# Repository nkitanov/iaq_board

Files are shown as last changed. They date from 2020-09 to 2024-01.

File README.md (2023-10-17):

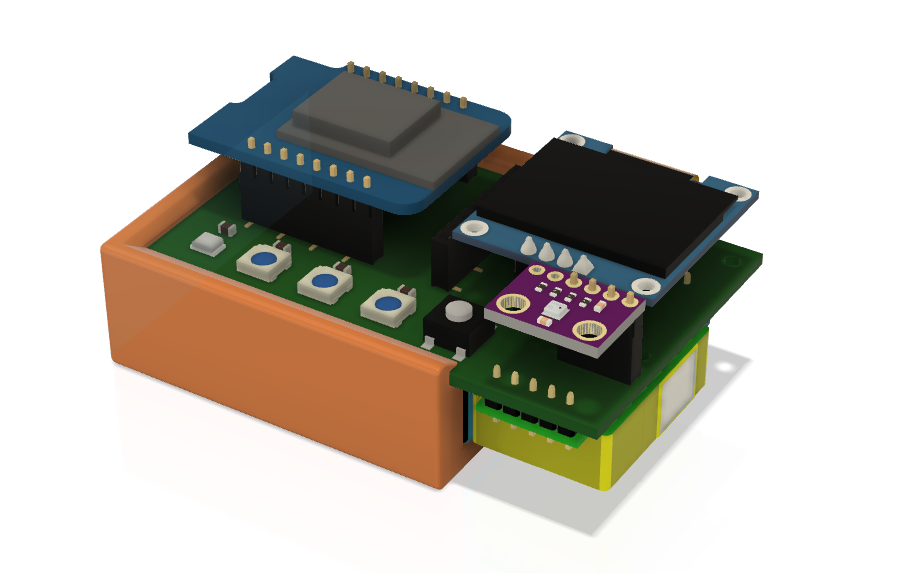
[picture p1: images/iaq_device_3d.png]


# IAQ (Indoor Air Quality) Board 
IAQ Board is a DIY (Do-It-Yourself) device for measuring internal air quality. I needed a device for measuring some air quality parameters which is **compact, cheap, simple and capable**. After I prototyped it, decided instead of mounting into some odd box with cables hanging inside between the sensors, why not just solder everything on a printed circuit board. I had some experience with this from the time when I was a student years ago and luckily now it's much easier to crate PCB and very cheap to get it printed. 

**And here is my device. I am publishing all the details and documentation under '[open source hardware](https://en.wikipedia.org/wiki/Open-source_hardware)' CC-BY-CA license, so everyone can build, adapt and sell it, as long as share under the same license**

**Table of Contents**
   * [IAQ (Indoor Air Quality) Board](#iaq-indoor-air-quality-board)
      * [What exactly is this thing?](#what-exactly-is-this-thing)
      * [Who can build it?](#who-can-build-it)
      * [What about ordering a device?](#what-about-ordering-a-device)
   * [Components Details](#components-details)
      * [1. PCB](#1-pcb)
      * [2. Holder case](#2-holder-case)
      * [3. Microcontroller Board](#3-microcontroller-board)
      * [4. Dust Sensor](#4-dust-sensor)
      * [5. CO2 sensor](#5-co2-sensor)
      * [6. Temperature/Humidity/Pressure sensor](#6-temperaturehumiditypressure-sensor)
      * [7. Ambient Light Sensor](#7-ambient-light-sensor)
      * [8. LEDs](#8-leds)
      * [9. Displays](#9-displays)
      * [10. Volatile Organic Compound sensor](#10-volatile-organic-compound-sensor)
      * [11. Other electrical components](#11-other-electrical-components)
      * [Can you skip components?](#can-you-skip-components)
   * [Bill of Materials (BOM)](#bill-of-materials-bom)
   * [Firmware](#firmware)
   * [Schematic](#schematic)
   * [Soldering tips](#soldering-tips)
   * [User manual](#user-manual)
         * [Multi function button](#multi-function-button)
         * [LED Brightness control and correction](#led-brightness-control-and-correction)
   * [FAQ](#faq)
            * [<em>Can I power it from a battery?</em>](#can-i-power-it-from-a-battery)
            * [<em>Can it be installed outdoors?</em>](#can-it-be-installed-outdoors)
            * [<em>How to calibrate MH-Z19B CO2 sensor?</em>](#how-to-calibrate-mh-z19b-co2-sensor)
            * [<em>How to calibrate SGP30 VOC sensor?</em>](#how-to-calibrate-sgp30-voc-sensor)
            * [<em>How to connect to WiFi?</em>](#how-to-connect-to-wifi)
            * [<em>How to add it in Home Assistant?</em>](#how-to-add-it-in-home-assistant)
            * [<em>What if some of the sensors/displays is disconnected while the device works?</em>](#what-if-some-of-the-sensorsdisplays-is-disconnected-while-the-device-works)
         * [<em>What about short circuits of the exposed electronics?</em>](#what-about-short-circuits-of-the-exposed-electronics)
   * [More Tech Details](#more-tech-details)
   * [Known issues](#known-issues)
   * [License](#license)

## What exactly is this thing?
The device is based on widely available and cheap essential components ([MCU](https://en.wikipedia.org/wiki/Microcontroller) and sensors). The core component is a simple [PCB](https://en.wikipedia.org/wiki/Printed_circuit_board) (printed circuit board) that's why I called it **IAQ Board**. The board integrates all the components in a very small footprint (size of a cigarette box). All parts are soldered on it and everyone can assemble it with basic soldering skills. The total price if you build it yourself is about 50-60 EUR. I also made simplistic holder for 3D print (6-7 EUR is you don't have a 3D printer). For these amount of money you get the following air parameters measured adequately (you might not install all sensors if you want to save money): 
- [X] ***Temperature / Humidity / Pressure***
- [X] [***Air particles PM1, PM2.5, PM10***](https://en.wikipedia.org/wiki/Particulates)
- [X] [***Carbon Dioxide with NDIR sensor***](https://en.wikipedia.org/wiki/Indoor_air_quality#Carbon_dioxide)
- [X] [***Air Quality Index by EPA, based on 24h average PM2.5 particles***](https://airindex.eea.europa.eu/Map/AQI/Viewer/)
- [X] [***Ambient light***](https://en.wikipedia.org/wiki/Illuminance)
- [X] [***Total VOC (volatile organic compound)***](https://en.wikipedia.org/wiki/Volatile_organic_compound)
- [X] ***equivalent CO2 (not very correct compared with the NDIR sensor, but it's provided by the VOC sensor)***

**On top of that:**
- [X] ***At least one OLED display to show the data (can have one more on the top of the MCU board)***
- [X] ***three RGB wide angle LEDs with auto brightness. LED1 indicates PM2.5, LED2 - Air quality index, LED3 - CO2.*** 
- [X] ***auto night dimming of the displays and LEDs (can be disabled)***
- [X] ***MIN/MAX values of Temperature, PM2.5 and CO2, and 24h average PM2.5 value.***
- [X] ***multi function button for selection of the data to show on the display***
- [X] ***[firmware](https://en.wikipedia.org/wiki/Firmware) based on [ESPhome](https://esphome.io/), the device can be [directly added](https://esphome.io/components/api.html) in [Home Assistant](https://www.home-assistant.io/)***
- [X] ***WiFi access to the device with http server and [REST API](https://esphome.io/web-api/index.html) and [esphome native API](https://esphome.io/components/api.html)  to read the sensor data***

Here is a video with all you need to know:

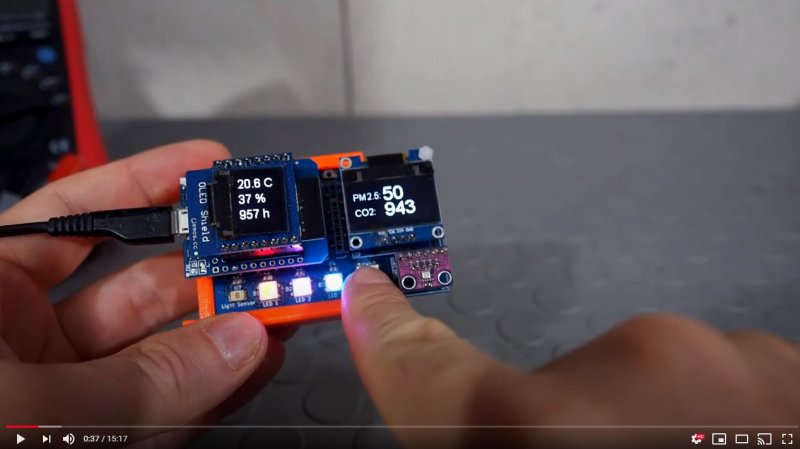
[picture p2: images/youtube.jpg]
Click to see the video (https://www.youtube.com/watch?v=X75OGs2TTT8)


## Who can build it?
The device is just a simple PCB board and almost everyone with some soldering skills can assemble it in a few steps:
1. [Download the PCB files](kicad/) and print the PCB somewhere like https://jlcpcb.com/
2. Buy some components (listed in the bill of materials section) from Aliexpress or any other source.
3. Solder everything on the board. With the exception of the ambient light sensor, all the rest is pretty easy with general soldering skills. Soldering light sensor can be done with regular soldering iron, but because of the small size of the IC, it's easier if you have heat gun or SMD reflow oven/plate. [Here is video how to complete device from assembled PCB.](https://www.youtube.com/watch?v=b2oDBgN3h1w)
4. Flash the microcontroller with the esphome firmware [following the manual](firmware/). You can write your own firmware if you have the skills. :smile: 
5. Print the holder case on 3D printer if you wish. I have some sensors without it and they are perfectly fine, so it's up to you.

If you have experience with electronics and microcontrollers just check the [schematics](kicad/) and make whatever you wish - build your own firmware, do another PCB, connect external sensors, don't use it at all because you can make it better :smile:. The device is quite simple for embedded electronics enthusiasts anyway...

## What about ordering a device?
I made this device for me and then decided to share it. I think a lot of people might be interested to have such air quality sensor. I did not have intension to make money from it, that's why it's "open hardware" and I publish all of the information, so everyone can build it. 

However I know that someone might be interested in the device, but lack the skills to build it. [Please follow this link for more details.](ordering.md)

# Components Details
The device with AAA battery size comparison:

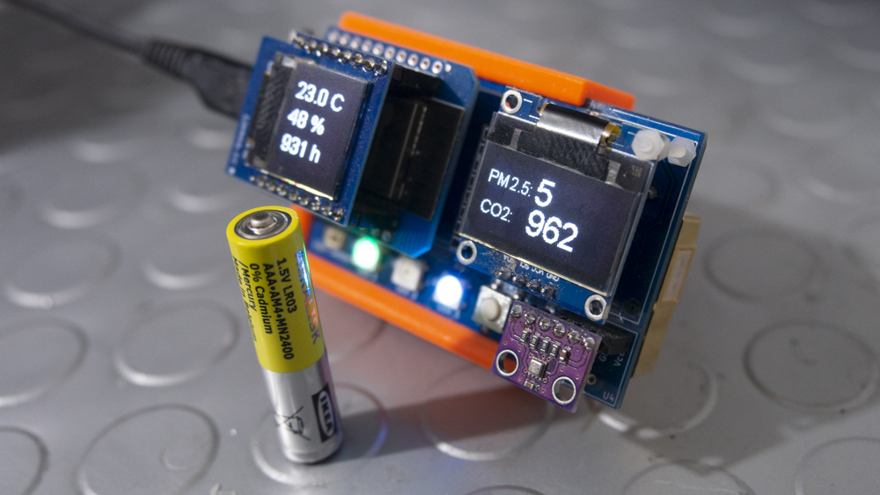
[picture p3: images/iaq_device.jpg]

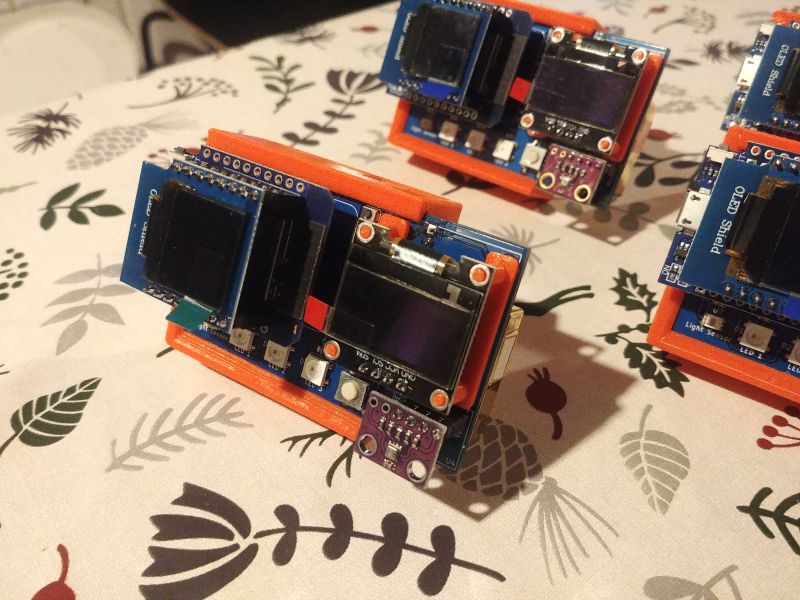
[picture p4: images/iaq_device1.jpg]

## 1. PCB
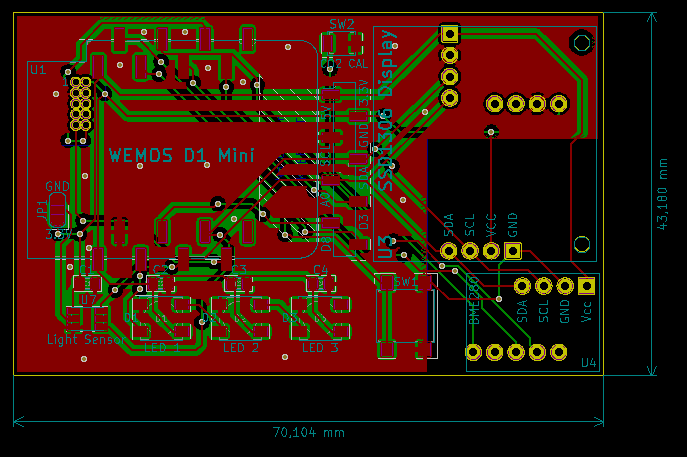
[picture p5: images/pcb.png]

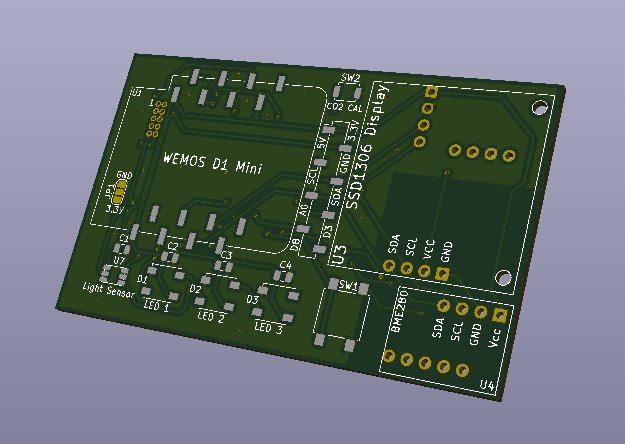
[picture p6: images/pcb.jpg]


The PCB (printed circuit board) is very simple and compact. It's 70x43mm (photos above are showing it larger than the actual size). It just connects a few sensors, microcontroller and displays. I wanted to integrate it in as much smaller footprint as possible, so the whole device is like a cigarette box. Most of the parts are surface mounted which makes the soldering just a bit more complicated, but still not a big deal. And of course it could be integrated even more by soldering all individual components on the PCB but then it's not really a hobby project anymore and much more difficult to build it.
It's designed on [KiCad](https://kicad.org/) and in the [kicad folder](kicad/) you can find full KiCad project, PCB gerber files, etc.
## 2. Holder case
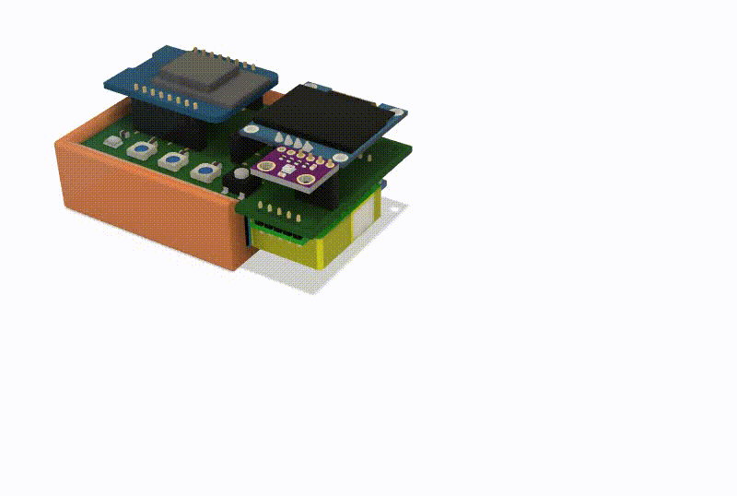
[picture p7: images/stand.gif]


For any device the box is important. However my idea was to expose the PCB and electronics as much as possible in order to simplify it. I like the "raw" view of electronics and in this form I find it beautiful. 

Taking into account this, I designed a simple holder case for "sliding" the PCB in it and holding the particle sensor. The case can stay at about 45 degrees angle. It is designed on Fusion 360 and the [details are here](case_model). The holder case is not perfect, I was thinking to redesign it but no time for this. I am sure someone can do it better. :smile: Or design a complete box to cover the electronics fully, for me it is better in this minimalistic style. 
## 3. Microcontroller Board
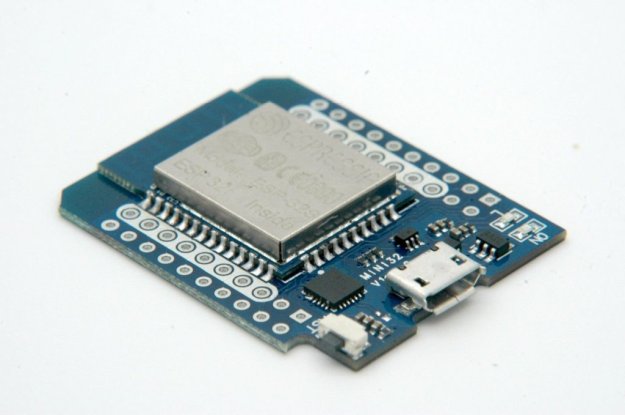
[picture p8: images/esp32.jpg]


Initially I developed the board with using the most popular WiFi enabled MCU [ESP8266](https://en.wikipedia.org/wiki/ESP8266) mounted on the cheap and small [Wemos D1 Mini board](https://docs.wemos.cc/en/latest/d1/d1_mini.html). However this MCU have some limitations described in the [tech details](#more-tech-details), so I changed it with the same size board compatible with Wemos D1 Mini, but running the newer much more powerful MCU of the same company - [ESP32](https://en.wikipedia.org/wiki/ESP32). In that way the device is quite stable, can run web server and since the board is having the same layout, on top of the D1 Mini ESP32 board you can connect extra display designed for d1 mini very easy. PCB is compatible with both D1 Mini ESP8266 or ESP32, even the labels are the same like on the older D1 board. However **I do not recommend to use D1 mini with ESP8266!** Also if I have to build next version of the PCB (I still have some 25 pcs), I will change the pins of one of the dust sensors.

These small size MCU board are pretty nice, they are tiny, have USB connector, onboard power supply and USB converter for programming or serial output. And you are powering the whole device just with a mini USB cable.
## 4. Dust Sensor
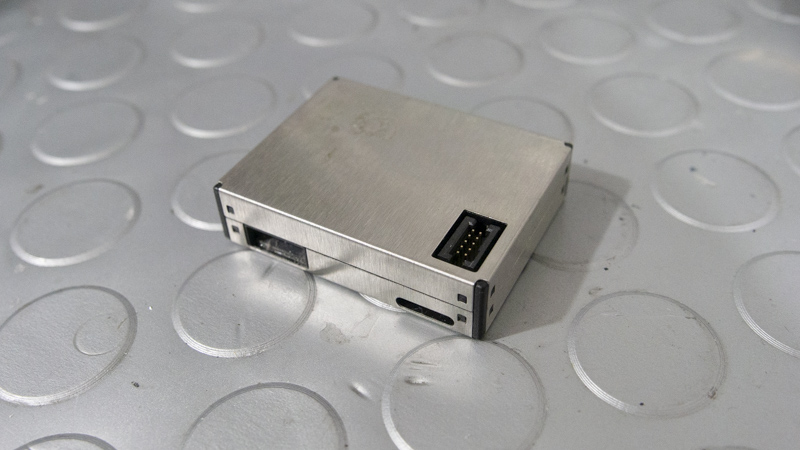
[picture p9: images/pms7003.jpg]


Dust sensor is the Chinese [Plantower PMS7003]([http://www.plantower.com/en/content/?110.html](https://www.plantower.com/en/products_33/76.html)) - 1, 2.5 and 10 micron particle laser sensor. It's very small and is perfect for indoor environment. 
## 5. CO2 sensor
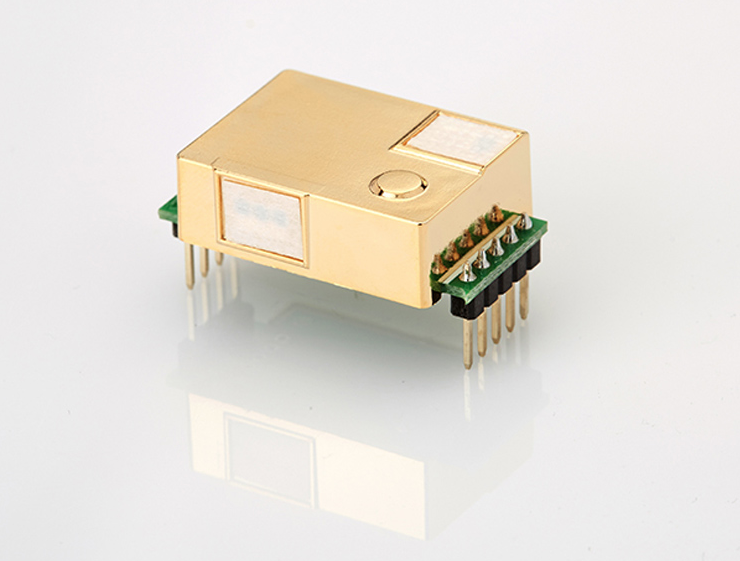
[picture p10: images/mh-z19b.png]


Carbon dioxide sensor is the Chinese [Winsen MH-Z19B](https://www.winsen-sensor.com/sensors/co2-sensor/mh-z19b.html) - the most expensive part of the device. It's quite popular for hobby air quality meters and can [adequatly measure](https://www.circuits.dk/testing-mh-z19-ndir-co2-sensor-module/) up to 5000 ppm CO2 concentration.

**Keep in mind that there are some fake MH-Z19B sensors, [explained here](https://revspace.nl/MH-Z19B#Fake_MH-Z19B_.28black_PCB.29).**
## 6. Temperature/Humidity/Pressure sensor
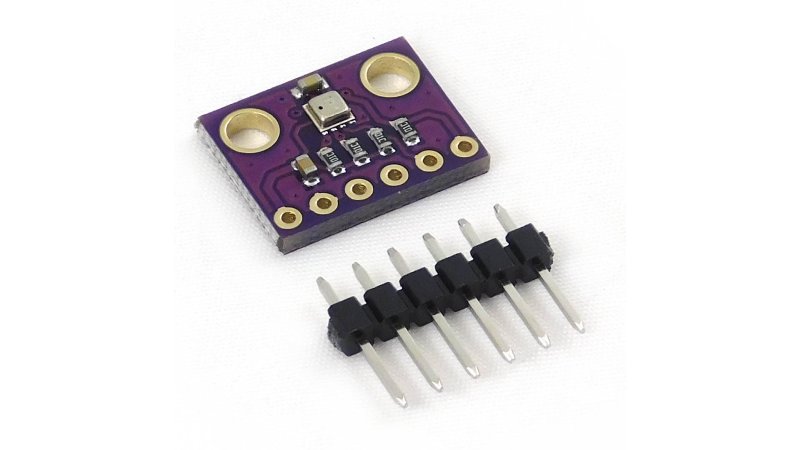
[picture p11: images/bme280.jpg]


This sensor is the popular [Bosch BME280](https://www.bosch-sensortec.com/products/environmental-sensors/humidity-sensors-bme280/), mounted on 3.3V only breakout board from China. There are also smaller [breakout boards](http://www.cncroutersource.com/breakout-boards.html) from China working both on 5V and 3.3V, but these have voltage regulator which can theoretically warm the board and change the temperature reading. That's why I use the boards with 3.3V only.

**Please note that due to semiconductor shortage these are difficult to find now (June 2021). I am currently using my own breakout where I solder the BME directly. BME280 as IC can be found occasionally in stock from DigiKey**
## 7. Ambient Light Sensor
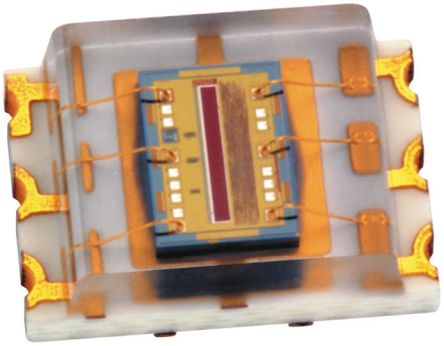
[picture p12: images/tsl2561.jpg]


The light sensor is [TSL 2561](https://ams.com/tsl2561) and it's the only sensor you need to solder directly on the board without a breakout board. I added this sensor not because I need to measure the ambient light but because I am a brightness freak, and I need the LEDs brightness to depend on the ambient light. Also wanted during the night when the lights are off the device to turn off the LEDs and displays automatically. You can also change the behavior of this brightness control and I spend some extra time developing the config only for the brightness features. :smile:
## 8. LEDs

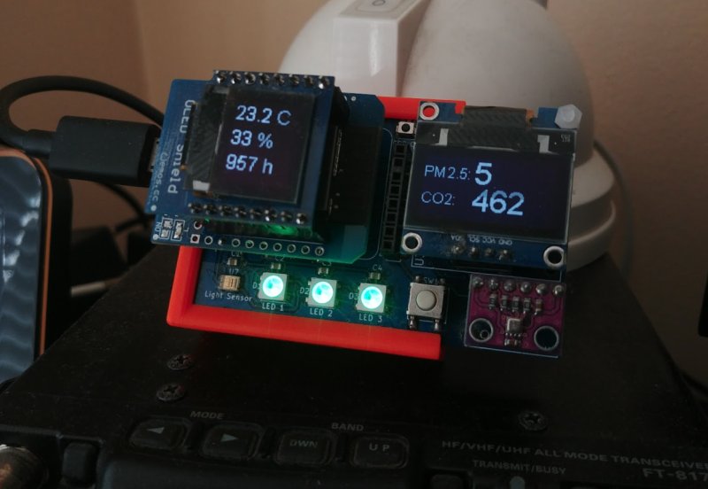
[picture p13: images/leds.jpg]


The device have three [Neopixel 5050](https://www.digikey.com/catalog/en/partgroup/neopixel-rgb-5050-led-with-integrated-driver-chip-100-pack/70939) RGB multicolor LEDs. These LEDs are mostly found in the colorful LED strips and are controlled over a single wire. In my esphome based firmware left LED color is indicating the level of PM2.5 and change the colors depending on the value. Middle (LED2) indicates Air Quality Index based on PM2.5 only and the right one (LED3) indicates CO2 value. Keep in mind PM2.5 values are close to [EEA](https://www.eea.europa.eu/) levels (especially AQI). Some other devices like Xiaomi Air Purifiers have some very high levels on their displays and logic - it's green up to 70 microns which is already considered unhealthy both by EEA and EPA. In China "healthy" is considered bellow 50 microns. That's why AUTO mode of these Chinese devices [works so bad](https://smartairfilters.com/en/blog/xiaomi-auto-mode-leaves-air-unsafe-86-hours/). I try to keep indoor PM2.5 around 5-10 microns. I normally control my purifiers by Home Assistant and do not rely on their auto logic. If you have Xiaomi Purifier it can still show green, and the iaq device shows stable red, but it is correct according to the EU regulations.

**Colors of the LEDs depends on this table:**
PM2.5 value (um/m3)<br>LED 1 | [AQI by EEA (Air Quality Index for PM2.5 24h average)](https://airindex.eea.europa.eu/Map/AQI/Viewer/)<br>LED 2 | CO2 value (ppm)<br>LED 3 | Color |  R  |  G  |  B
:-----------------: | :-------------: | :-------------: | :---: | :-: | :-: | :-: 
< 10 | < 10 (Good) | < 700 |  | off | on | off 
11 - 20 | 10 - 20 (Fair) | 700 - 1000 |  | off | on | on 
20 - 30 | 20 - 25 (Moderate) | 1000 - 1500 |  | on | on | off 
30 - 40 | 25 - 50 (Poor) | 1500 - 2100 |  | on | off | on 
\> 50 | > 50 (Very Poor) | > 2100 |  | on | off | off 

## 9. Displays
The main display is the popular SSD1306 128x64 OLED display. On the top of the MCU board you can install extra [OLED 63x48](https://docs.wemos.cc/en/latest/d1_mini_shiled/oled_0_66.html) shield from Lolin which shows temperature, humidity and air pressure only.
## 10. Volatile Organic Compound sensor
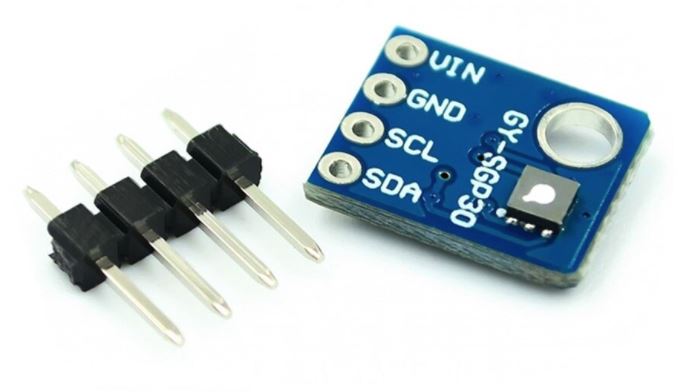
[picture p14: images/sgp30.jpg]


This is the [Sensirion SGP30](https://www.sensirion.com/en/environmental-sensors/gas-sensors/sgp30/) senor mounted on a breakout board from China. I do not use it on all my devices, but I added it because I can. :smile: Also with it the device measures almost completely the internal air quality. SGP30 is also showing equivalent CO2 based on VOC but it's not precise compared with MH-Z19B NDIR sensor. Also it needs periodic calibration hardcoded in the firmware which makes it more tricky to use.

Please [check here](https://github.com/nkitanov/iaq_board/issues/10#issuecomment-798994427) for the known issues with these boards.
## 11. Other electrical components
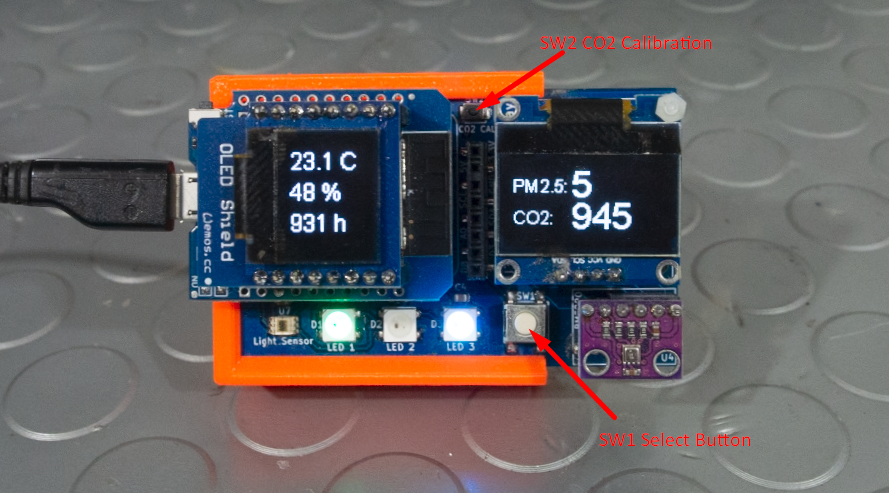
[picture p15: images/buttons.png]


The device have 2 buttons - one for selection screens and settings, and another micro button for calibration of the CO2 sensor to 400ppm if you keep it pressed for more than 7 sec. 

There are also four [surface mounted](https://en.wikipedia.org/wiki/Surface-mount_technology) [bypass capacitors](https://en.wikipedia.org/wiki/Decoupling_capacitor) for the ambient light sensor and the LEDs.

## Can you skip components?
Yes. The minimum you need is the [microcontroller board](#3.-microcontroller-board). However since you don't have any sensors, you won't get any data. :smile: You can add only the sensors needed. Also if you skip ambient light sensor there will be no auto brightness control and the LEDs will operate always at 25% intensity. Installing only the ambient light sensor without any of the displays or any of the other [I2C](https://en.wikipedia.org/wiki/I%C2%B2C) sensors (BME280, SGP30) will not work as there are no [pullup resistors](https://en.wikipedia.org/wiki/Pull-up_resistor) on the PCB for the I2C bus since it uses the resistors of the external breakout boards.

# Bill of Materials (BOM)
Bellow is the list of all parts needed to assemble the device with links to sources where you can get them. Of course other sources can be used, just pay attention that the items are identical with the listed bellow. For example the SSD1306 display can be found with similar physical look and dimensions, but pins are not the same.

Schematic Ref | ITEM | pcs | Comment
--------------| ---- | :-: | -------
| | PCB Board | 1 | in [kicad folder](kicad) you can find all the data and GERBER PCB design files
U1 | [WeMos_D1_mini_ESP32](https://www.aliexpress.com/item/4000880936043.html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,searchweb201602_,searchweb201603_) | 1 | [ESP8266 version](https://www.wemos.cc/en/latest/d1/d1_mini.html) also can work but not recommended 
U2 | [PMS7003 Sensor](https://www.aliexpress.com/item/32832444694.html?spm=a2g0s.9042311.0.0.27424c4dKxsO6Z) | 1 | don't use the 2x5pin 1.27mm receptacle which comes normally wit these sensors, explanation is bellow
U3 | [SSD1306 Display](https://www.aliexpress.com/item/32956051129.html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,searchweb201602_9,searchweb201603_55) | 1 | pay attention to correct pin order if you are buying from another source, as there are similar 4pin boards with different pinout
U4 | [BME280 breakout board](https://www.aliexpress.com/item/4000166540445.html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,searchweb201602_9,searchweb201603_55) | 1 | only 3.3V version with 6 pins which have both I2C and SPI. **Please note that due to semiconductor shortage these are difficult to find now (June 2021). I am currently using my own breakout where I solder the BME directly. BME280 as IC can be found occasionally in stock from DigiKey**
U5 | [MH-Z19B Sensor](https://www.aliexpress.com/item/1005001865093513.html?spm=2114.12010610.8148356.5.5b7387a5ZmuUlX) | 1 | **Beware for fake sensors, as [explained here](https://revspace.nl/MH-Z19B#Fake_MH-Z19B_.28black_PCB.29). Buy from Winsen official store in Aliexpress.**  
U6 | [SGP30 breakout board](https://www.aliexpress.com/item/4000004614708.html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,searchweb201602_9,searchweb201603_55) | 1
U7 | [TLS2561 light sensor](https://www.aliexpress.com/item/33056165996.html?spm=a2g0s.9042311.0.0.15314c4draqb6x) | 1
C1-C4 | [0.1 uF SMD Capacitor](https://bg.farnell.com/wurth-elektronik/885012207016/cap-0-1-f-10v-10-x7r-0805/dp/2534051?st=smd%20capacitors) | 4
D1-D3 | [Neopixel 5050 LED](https://www.aliexpress.com/item/4000750610574.html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,searchweb201602_,searchweb201603_) | 3
| SW1 | [Tactile Switch B3S-1000](https://uk.farnell.com/omron/b3s-1000/switch-spno-0-05a-24v-smd/dp/177807) | 1 |
| SW2 | [Tactile Switch B3U-1000P](https://bg.farnell.com/omron/b3u-1000p/switch-spst-no-0-05a-12v-smd/dp/1333652?st=B3U-1000P) | 1
| | [PCB Receptacle, 1.27 mm, 10 Contacts](https://bg.farnell.com/amphenol-icc-fci/20021311-00010t4lf/receptacle-vert-1-27mm-tht-10way/dp/1865313) | 1 | This PCB Receptacle is for connecting PMS7003 dust sensor. Keep in mind these sensors come with such connector included but it's slightly taller and makes a gap of about half mm between sensor and PCB which is not ok.
| | [SMD PCB Receptacle 8 pins](https://uk.farnell.com/samtec/ssm-108-l-sv/receptacle-2-54mm-vert-8way/dp/1668259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) | 3 | two are needed for the MCU board, 3rd you can skip. It's for extra pins on the PCB but with ESP32 MCU not needed so much as extra headers can be soldered directly on it's board
| | [PCB Receptacle 4 pin](https://uk.farnell.com/samtec/bcs-104-l-s-te/receptacle-2-54mm-vert-4way/dp/1667470?ost=bcs-104-l-s-te) | 4 | four is needed if all sensors are installed
| | [OLED 63x48 shield](https://www.aliexpress.com/item/32981156326.html?spm=a2g0s.9042311.0.0.27424c4dO21RuC) | 1 | not required, only if you want an extra display on top of the MCU board
| | [Holder case](case_model) | 1 | it's not required to have it but it makes the device completed
| | [Display holder](case_model) | 1 | This small 3D printed part is holding tight the display from flapping 
| | [Various 2.54 headers](https://www.ebay.co.uk/itm/10pcs-40-pin-2-54mm-Breakaway-Male-Header-for-PCB-Breadboard-1x40-Single-Row-UK/262755464818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) | | You will need these for the CO2 sensor if you don't have available. Normally they come together with the breakout boards.
| | [2mm nylon bolts/nuts](https://www.ebay.co.uk/sch/i.html?_from=R40&_trksid=p2047675.m570.l1313&_nkw=2mm+nylon+bolts&_sacat=0) | | If you want to make the display more stable you can install nylon bolts like explained [in the video](https://youtu.be/b2oDBgN3h1w?t=758). Better use [display holder](case_model).

# Firmware
Firmware is created with [ESPHome](https://esphome.io/index.html). The binary file, configuration and instructions are located in [firmware folder](firmware/).

# Schematic
Find all KiCad project in [kicad folder](kicad/) with schematic, PCB design file, 3D models, etc. In schematic U1 (microcontroller board) is based on ESP8266 version (original Wemos D1 mini).
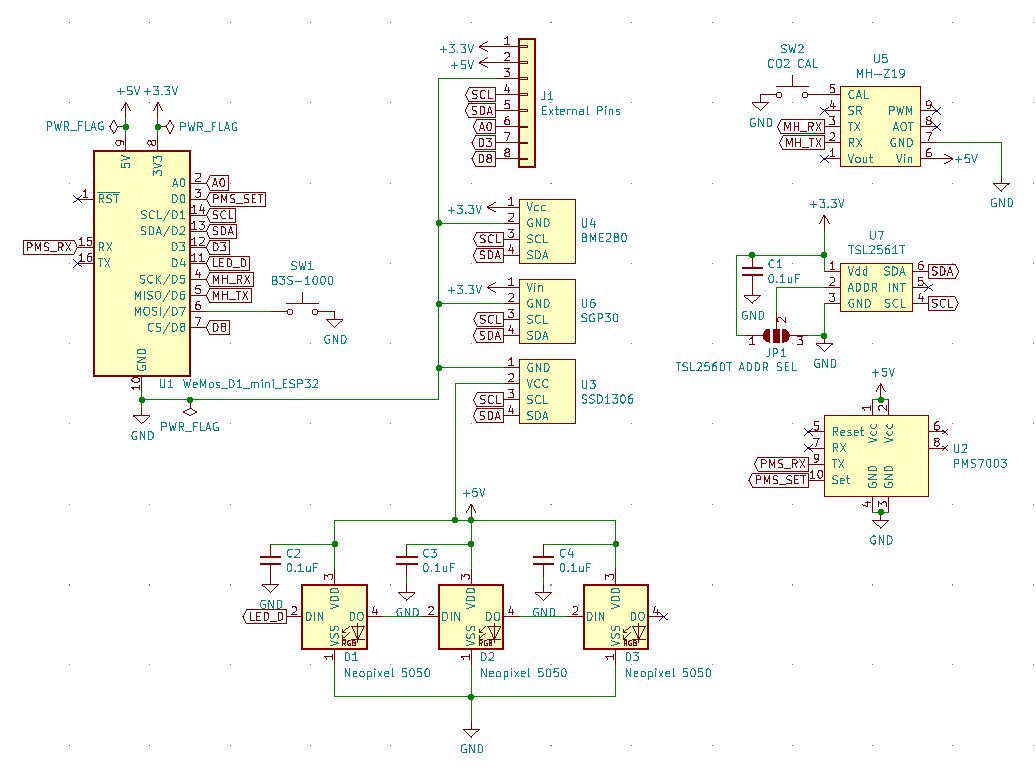
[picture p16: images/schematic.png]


# Soldering tips
You need basic soldering skills and a soldering iron with thin tip. Because most of the components are SMD, it's much easier to buy some [solder paste](https://en.wikipedia.org/wiki/Solder_paste) if you don't have. Most of the SMD components are quite large to solder easily with the iron, you [can look in youtube](https://www.google.com/search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), there are thousand of videos how to solder SMD components. Of course for some parts it's easier to use hotair rework station but not a requirement.

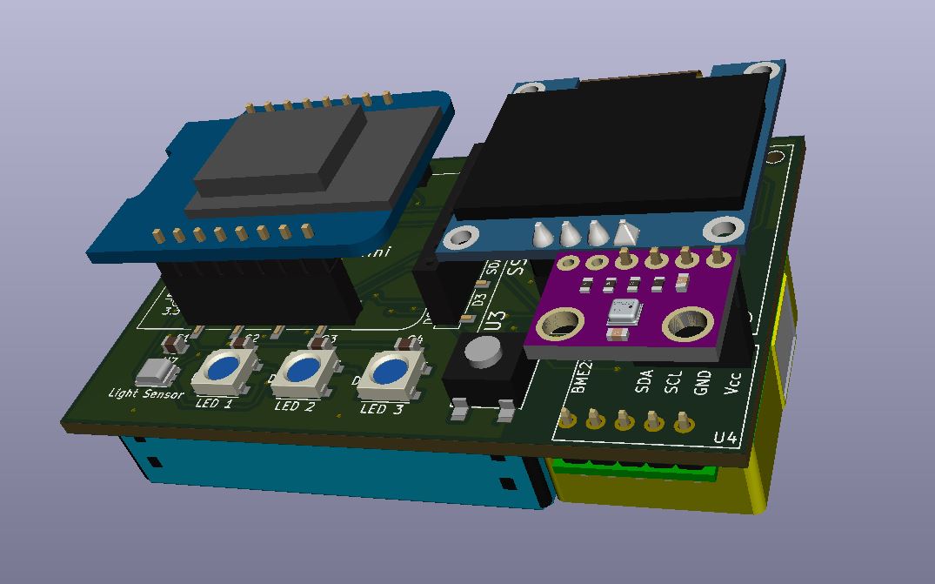
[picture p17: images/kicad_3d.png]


The only more difficult component to solder is the ambient light sensor which is quite small. I normally do these with a thin layer of solder paste and heatgun from bellow. However because of the footpint on the PCB is purposely made a bit bigger, I managed to solder it as well with a regular iron with a thin tip and solder paste. Also magnifying glasses will help.

If you use the small display over the MCU board, make sure i2c address is configured as 0x3D, which means to solder bottom two pads of the solder jumper like here:

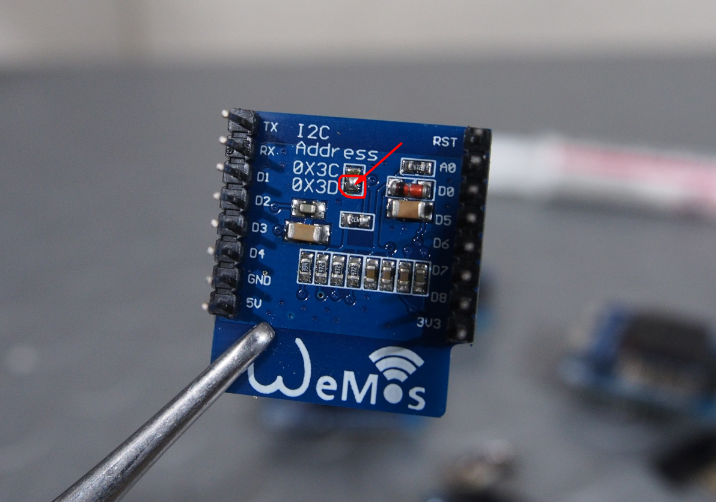
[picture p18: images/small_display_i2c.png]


# User manual
It's quite simple, the device have only one "multi functional" button SW1, and one micro button SW2 for calibration of the CO2 sensor.

### Multi function button
- Short press "rotates" the data displayed on the right bigger display. By default it starts showing only PM2.5 and CO2 with larger fonts as these are the most important air quality parameters. This is also the default "screen" and every time the device is restarted it will show that screen. The display is quite small (128x64 pixels) so some of the text is shortened like P1 (for PM1), C (for CO2), etc. Each short press of the button rotates this sequence:
```
DEFAULT==================================================================MIN/MAX===============
PM2.5      AQI        Temperature    PM1         Amb.Light  PM1         Temp. MIN        Displays OFF
CO2 ----> Index ----> Humidity ----> PM2.5 ----> TVOC ----> PM2.5 ----> PM2.5 MIN ----> (both displays  
 ^      PM2.5 24h     Pressure       PM10        eCO2       PM10        CO2 MIN          turned off)
 |                                                          Temperature Temp. MAX             |
 |                                                          Humidity    PM2.5 MAX             |
 |                                                          Pressure    CO2 MAX               |
 | _ _ _ _ _ _ _ _ _ _ _ _ _ _ _ _ _ _ _ _ short click_  _ _ _ _ _ _ _ _ _ _ _ _ _ _ _ _ _ _ _|
```

- Press and hold the button from **2 to 5 sec**: On the display you see `LEDs status: OFF`. This means the status LEDs will be tuned off. Do the same to toggle back to `LEDs status: ON`. This setting is saved in the non volatile memory, so it will keep it's setting even if the MCU is restarted. 
- Press and hold the button from **5 to 10 sec**: On the display you see `Night dim: OFF`. This means the LEDs and displays will not be turned off if ambient light fall under 2 lux. Do the same to toggle back to `Night dim: ON`. This setting is saved in the non volatile memory, so it will keep it's setting even if the MCU is restarted. 
- Press and hold from **10 to 15 sec**: On the display you see `MIN-MAX Reset!`. It reset the minimum and maximum values of temperature, PM2.5 and CO2 on screen 6. Please note these resets each time the device is restarted. Keep in mind that 1.5 min after boot and reset, values of CO2 and temperature might not be correct.
- Press and hold from **15 to 20 sec**: It will increase LED brightness correction with +5%. When it reaches +40% another press and hold will make it 0% again. 
- Press and hold from **20 to 30 sec**: On the display for 20 sec it will show the following diagnostic data:
```
YAML ver: (shows version of the esphome yaml config)
ESPHome ver: (ESPHome version which build the firmware)
IP: (IP address if connected to WiFi)
Connected to: (SSID of the wifi, if connected)
LED brightness: (brigtness correction of the LEDs)
```
### LED Brightness control and correction
Led brightness is controlled periodically (each 3 sec), proportional of the ambient light measured by the TLS2561 sensor. If there is no ambient light sensor installed LEDs are constant at 25%, but auto turn off will also not work. Logic of this simple auto control is configured in [this code](firmware/includes/brightness.yaml).

Also by default setting of these LEDs are to begin from 11% brightness. If it's bellow 11% they are turned off. As mentioned in the LED description setting these Chinese LEDs comes with different intensity and the ones listed in Bill of Materials section are too weak at the lowest setting. That's why I added brightness correction setting which can go from 0% to +40% in 5% step. This be done with press and hold the multi function button from 15 to 20 sec (explained above). This setting is saved in the non volatile memory of the MCU and it does not have to be configured after each reset. Alternatively if the device is added in Home Assistant, you will see a template switch called `brightness_correction`, which is doing exactly the same thing as the button on pin.

# FAQ
#### *Can I power it from a battery?*

The device is powered from regular micro USB cable with 5V and consumes between 100-250 mA. You can power it with USB battery pack but not for too long (for example 4000 mAh battery will be depleted in about 20h). If you need to operate it from a battery, firmware have to enter the MCU in a [deep sleep](https://esphome.io/components/deep_sleep.html) mode periodically. You have to build your own firmware. I do not run any of my devices in deep sleep as I do not see a reason for that.
#### *Can it be installed outdoors?*

The device is not waterproof. It can run outdoors if you install it in enclosure which is protecting it from water. It can handle high humidity maybe (never tested it). However the main purpose of the device is to be an internal air quality monitor. Measuring CO2 and VOC outside does not makes too much sense, but it can be used for dust pollution monitoring.

#### *How to calibrate MH-Z19B CO2 sensor?*

Periodically (let's say one time per month) and after installation of a new sensor calibration needs to be performed. The calibration is done by exposing it to the outside air which have about 400ppm CO2 concentration for about 20-30 min and then press and hold the micro button SW2 for more then 7 sec. In that way the value of the sensor is "zeroed" at 400 ppm. Alternatively if the device is added in Home Assistant, there is a template switch called `switch.co2_sensor_zero_calibration` and you just turn it on. It's doing the same as pusing the button but you are doing it remotely over the WiFi. [Here](https://www.circuits.dk/testing-mh-z19-ndir-co2-sensor-module/) are more details about this sensor and calibration.

#### *How to calibrate SGP30 VOC sensor?*

It's explained in [ESPHome manual](https://esphome.io/components/sensor/sgp30.html). You need periodically to update the firmware which is quite easy if you use Home Assistant. In my initial tests I noticed even without calibration value, the sensor shows some values and can detect smells, alcohol vapors, etc. 

#### *How to connect to WiFi?*

After 1 minute of unsuccessful WiFi connection attempts, the microcontroller will start a WiFi hotspot with name `iaq_device` and password `12345678`. When you connect to this fallback hotspot, the web interface should open automatically (see also login to network notifications). If that does not work, you can also navigate to http://192.168.4.1/ manually in your browser. Then type name and password of your local wifi hotspot, click save and MCU will restart and try to connect to the provided network. Additionally from this captive portal you can upload a new firmware.

#### *How to add it in Home Assistant?*

If you have Home Assistant you have to [install the ESPHome addon](https://esphome.io/guides/getting_started_hassio.html), and after that [add the device](https://esphome.io/components/api.html). All sensors, switches, LEDs will appear automatically as entities in Home Assistant. Then you can add them on the dashboard, here is one of my devices added on Home Assistant dashboard with all data from it.

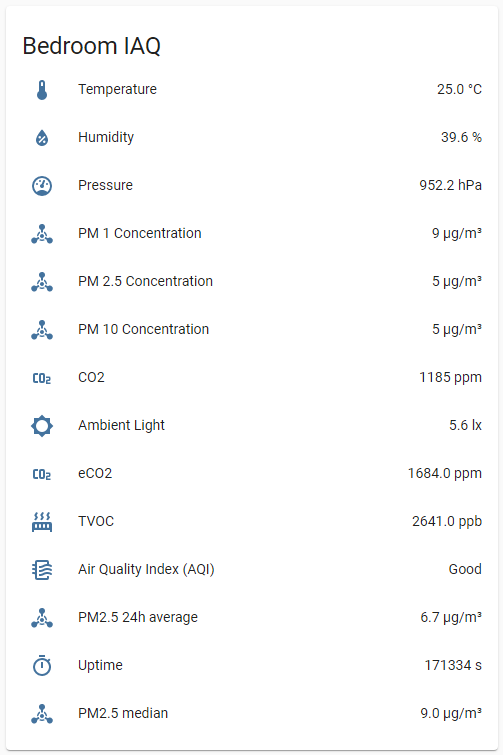
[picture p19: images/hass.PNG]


#### *What if some of the sensors/displays is disconnected while the device works?*

Some of the sensors can be accidentally disconnected as on the original design they are not soldered on the PCB but are connected on a header receptacle. No worries with that. On the display you will see `NaN` and it means there is no value from the sensor or it's out of boundaries. Just reseat the sensor and push the reset button on the MCU board or  disconnect and reconnect the USB cable.

### *What about short circuits of the exposed electronics?*

Since all the components are exposed, there is some risk of making a short circuit with a metal object. The power supply is just 5V with limited current so it shouldn't be a big worry. However be careful not to short circuit anything with a conductive object as theoretically this can damage a component. 

# More Tech Details

As I mentioned above the initial design was based on ESP8266 microcontroller. Because of that the PCB is developed for [Wemos D1 Mini board](https://docs.wemos.cc/en/latest/d1/d1_mini.html). Later on I decided it's much better to use ESP32 version, but PCB is not yet redeveloped and PCB silkscreen (writings) is for Wemos D1 Mini with esp8266. 
- J1 external pins was added for some extra pins available on Wemos D1 Mini for eventual connection of external sensors, inputs and outputs. These are all free left pins on esp8266 version. ESP32 version of D1 mini have 2 rows of pin which are directly usable and since there is no place on the PCB, only J1 will stay. The designations D8, D3, A0 are matching Wemos D1 mini ESP8266
- Because of the limitations with only one hardware UART port (which is physically available only on 2 specific pins) of the ESP8266, the dust sensor is using the hardware pins, which are shared with the Wemos D1 USB to UART converter. As a result the uart output of the firmware is disabled and it's not possible to flash the device over USB while it's connected on the PCB. It needs to be disconnected from the PCB and then it can be flashed over the USB. On ESP32 there are 3 dedicated hardware UARTs configuarable on any pin so if I do a next version of the PCB, it will be only for ESP32 and I will free up the USB converter ports for debugging. 
- In the description of [WeMos_D1_mini_ESP32](https://www.aliexpress.com/item/4000880936043.html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,searchweb201602_,searchweb201603_) the pins for UART0 are crossed (TX is where RX is shown). It's easy to fix as you can select those pins but if you carefully check the pins you might wonder why is that.
- If ESP8266 version is used there is no second dedicated hardware UART (we need two - one for dust sensor, and one for CO2 sensor). As a result the second one is "software" UART port, which uses [bit banging](https://en.wikipedia.org/wiki/Bit_banging). in combination with the WiFi activity it causes periodic WDT resets of the MCU - sometimes a few times for a few hours which is annoying. And this is one of reasons I use ESP32 now and do not recommend ESP8266.
- on the PCB there are no pullup resistors on the I2C bus. All breakout boards have these pullup resistors, so even attaching only one is enough. However if we install only the ambient light sensor and nothing more, it won't work because there will be no pullups. Also if you add more i2c breakout boards keep an eye of the resistance as it will drop with each extra resistor like [described here](https://www.bluedot.space/tutorials/how-many-devices-can-you-connect-on-i2c-bus/).
- ESP8266 is quite unstable if you try to use AP mode, also enabling http server is too much for this processor. That's why - don't use it, use only ESP32. :smile:
- JP1 solder jumper is for changing i2c slave address of the ambient light sensor. In the datasheet of the sensor are described the different configuration. The default address is when JP1 is not soldered.

# Known issues
These are valid for ESP32 MCU:
- Poor quality of the SGP30 VOC sensor breakout boards from China. The issues and fixes [explained here](https://github.com/nkitanov/iaq_board/issues/10#issuecomment-798994427).
- When you open [the web interface](https://esphome.io/components/web_server.html) of the device - it resets sometimes.
- I had a batch of Neopixel 5050 LEDs which are a bit brighter than the one linked in the BOM section and sometimes they switch to white color and 100% intensity. This is fixed in max 3 sec when correct color and brightness is set back again. These LEDs are set sequentially by their protocol so apparently it interprets wrongly set command or something. This is not happening with the LEDs linked in BOM but keep it in mind that it can happen with some LEDs (especially if they are from a bright batch).
- In the configuration I run the temperature with -1 degreeC offset. I found out these sensors shows a bit higher, and also there is some minimal temperature rise from conducted heat from the PCB. Always connect the BME280 sensor high above the PCB as in my design with the 4 pin receptacle. If you solder it lower on the PCB it might run hotter. For even more precise temperature measurement you can calibrate in esphome the value very precisely if you have access to calibrated thermometer. I was thinking also to experiment with thermocouple on the hole of the dust sensor fan so it can not pick up extra heat. This is in case if you need to use this temperature as input for a thermostat, as I do. 

These are valid for ESP8266 MCU (including the previous issues), not recommended to use that MCU because of the bellow issues:
- periodic [WDT resets](https://en.wikipedia.org/wiki/Watchdog_timer) depending of the WiFi activity, if MCU not connected to WiFi, it's ok. This is caused by the bit banging of the UART interface.
- web server is almost unusable as it needs a lot of memory which is not available on this tiny MCU
- unstable [AP fallback mode](https://esphome.io/components/wifi.html#access-point-mode), causing WDT resets, so sometimes not easy to connect to WiFi without hardcoding the credentials in the firmware

# License 
The device is [Open-source hardware](https://en.wikipedia.org/wiki/Open-source_hardware), [licensed by Open Source Hardware Association](https://certification.oshwa.org/bg000078.html). 

- Hardware is licensed under [CERN-OHL-W v2](https://ohwr.org/cern_ohl_w_v2.txt).
- Software is licensed under [Apache License 2](https://www.apache.org/licenses/LICENSE-2.0)
- Documentation is licensed under [CC-BY-SA-4.0](https://creativecommons.org/licenses/by-sa/4.0/). 



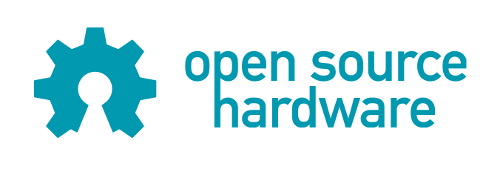
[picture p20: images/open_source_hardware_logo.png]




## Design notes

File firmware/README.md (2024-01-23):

# Firmware

Firmware is created with [ESPHome](https://esphome.io/index.html) -  it is a system to control your ESP8266/ESP32 by simple yet powerful configuration files and control them remotely through Home Automation systems.

I am not going to explain in details [the configuration yaml file.](iaq_board.yaml) If you want to modify it, you need to get familiar with esphome. The config file is fairly complicated compared with the usual esphome configurations, so there is some steeper learning curve, especially if you never programmed an MCU before. However by using esphome, you can build very complex logic without writing a single line of code, as the whole instruction is in the yaml config file. It's amazing how much time it saves!

- [`iaq_board.yaml`](iaq_board.yaml) - this is the configuration for esphome
- [`iaq_board.bin`](iaq_board.bin) - this is the binary file of the compiled firmware and can be directly uploaded in the MCU

## How to flash (or program) the controller?
1. Download [the bin file](iaq_board.bin) on your PC.
2. Install [esphome-flasher](https://github.com/esphome/esphome-flasher).
3. Connect the MCU board with mini USB cable not yet connecting it on PCB.
4. Start esphome-flasher, select the correct COM port which is the MCU as [explained here](https://esphome.io/guides/faq.html#i-can-t-get-flashing-over-usb-to-work) and flash it.

***That's it! Connect the MCU on the board, then power it on and it should work.***

If you want to go deeper, [follow the instructions](https://esphome.io/guides/getting_started_command_line.html) how to build the binary file from the yaml and upload it to the MCU from command line.

# Changelog
###  yaml 1.1.3 / 21 Mar 2021
- update esphome to 1.16.2
- default brightness correction set to +15%
  
###  yaml 1.1.4(?) / 23 Jan 2024 (Badn1nja)
- Fixed complication bugs (utime_sensor)
- updated/working with esphome: 2023.12.9
- Added Virtual buttons for automation and 'remote control' (Adds controls away from physical buttons)
- Changed Physical Button ID to buttonpcb (allows buttons to be added to yaml, not used before this change)
- Added Home Assistant Yaml for Automating the screen changes
- Added latest bin file using template yaml (Reccomend to use esphome to build)
- Added icons
- Re-formatted YAML for better readability and more inline with default esphome config

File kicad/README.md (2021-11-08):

# KiCad project design


This folder contains [KiCad](https://www.kicad.org/) project in [iaq_device folder](iaq_device) - schematic, [datasheets](iaq_device/datasheets) and [gerber](iaq_device/plot) files.

In order to print the PCB you have to zip all files from plot folder, these are the gerber files. Then upload the zip like [explained here](https://support.jlcpcb.com/article/21-how-do-i-place-an-order) for JLCPCB.

In the folder [my_libs](my_libs) are the custom footprint and symbol libraries, 3D models for kicad 3D viewer.





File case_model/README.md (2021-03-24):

# Stand Case (Holder Body)



The stand is created with [Fusion 360](https://www.autodesk.com/products/fusion-360/overview), here is the shared file design: https://a360.co/2STg8GN. The PCB slides in it and holds the particle sensor.

You can download directly the 3D models step files and print them on a 3D printer:
- [Stand_body.stl](Stand_body.stl) - this is the main body in which the assembled PCB "slides"
- [display_holder_22mm.stl](display_holder_22mm.stl) - this is a small 3d model to install bellow the display. It have 2 small pins for attaching to the PCB. It holds firmly the display from flapping in the receptacle. Keep in mind that it's for displays with holes 22mm each other. There are some other displays with bigger distance. 
- [Stand_pin.stl](Stand_pin.stl) - this is the small pin which is put in to the bottom of the stand and the body can be positioned at about 45 degrees. There is also a hole on the side of the body where the pin can stay when not used

Stand body:
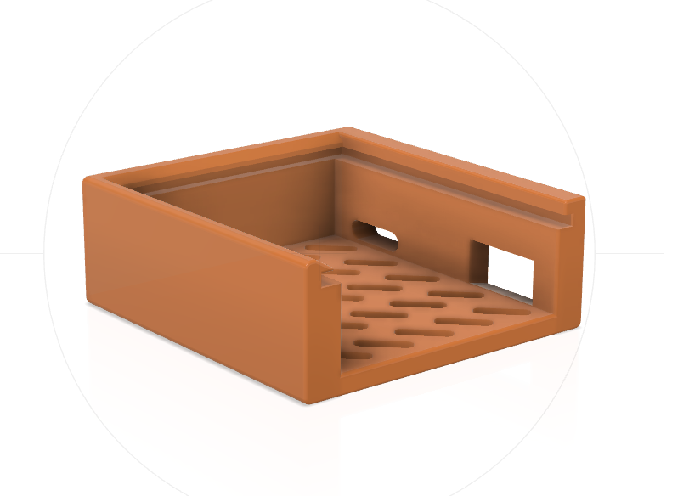
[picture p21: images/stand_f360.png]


Display holder:
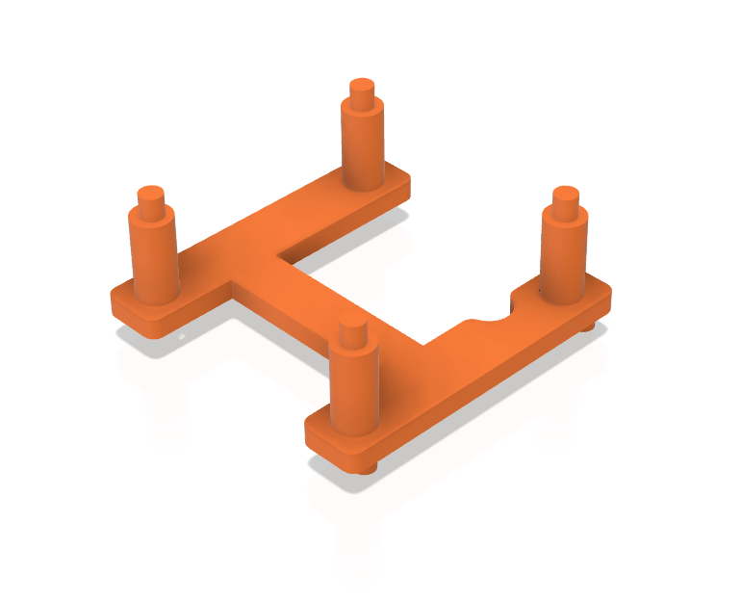
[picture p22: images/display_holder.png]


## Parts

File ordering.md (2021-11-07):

# Ordering

I got some emails from people interested in buying the device, and here are the details in the bellow table. Please note that I do not make this device for mass production and the bellow prices are considered fair for the efforts I need to invest in organizing ordering and building the devices. If you build it yourself it will cost about half these prices with most of the parts from China stores like Aliexpress. 

***Note 1 Oct 2021:** I stop producing fully assembled devices. I need focus on another things to do and I am very limited with time to keep the stock of parts. Also the prices of components is constantly increasing and some of them difficult to find. I will continue with making the fully assembled PCBs with all the  parts until I have components in stock and eventually until there is interest. Also I have some available BME280 breakout boards which I assemble myself.* 

Item | Price (EUR) | Notes 
:-----------------: | :-------------: | :------------- |
[PCB only](#PCB-only) | 5 | You have to order and solder all components yourself.
[Fully assembled PCB without sensors, but including the ambient light senor](#Assembled-PCB) | 35 | with high quality Samtec receptacles and Omron switches. You have to order all the other components yourself and solder the MH-Z19 sensor on the PCB.
BME 280 breakout board | 8 | These boards are 4 pin, only I2C and only 3.3V compatible with the board, i2c address can be changed. I assemble them myself as BME280 is difficult to get from Aliexpress.
[~~Fully assembled PCB with everything except SGP30, MH-Z19B and PMS7003 sensors, incl. displays and ESP board~~](#Fully-assembled-excluding-3D-printed-holder) | ~~70~~ | ~~You need to order and plug the dust sensor and MH-Z19B sensor yourself~~
[~~Fully assembled PCB with everything except SGP30 VOC sensor~~](#Fully-assembled-excluding-3D-printed-holder) | ~~92~~ | ~~I rarely use this sensor, that's why adding this option. No case.~~
[~~Fully assembled PCB excluding SGP30 VOC sensor + holder~~](#Fully-assembled-excluding-3D-printed-holder) | ~~99~~ | ~~Complete device plus case excluding SGP30 VOC sensor.~~
[~~Fully assembled PCB incl. everything + holder~~](#Fully-assembled-device-with-holder) | ~~105~~ | ~~this is the complete device~~ **\*** 
[Case holder, PETG material](#Case-holder)  | 7 | color orange only at the moment (like on the photo)

\* *I do not provide completely assembled board with SGP30 TVOC sensor anymore because of the poor quality of these boards ([explained here](https://github.com/nkitanov/iaq_board/issues/10#issuecomment-798994427)), you can buy yourself this board if TVOC is needed.*

***These prices exclude shipping. If you are interested in ordering, please send me an email to nkitanov@gmail.com with your address and I will let you know when the device can be ready as I might not have all parts.***

*Shipping is 7 EUR for one device with registered post, there are other faster options upon request. Payment is with bank transfer (preferably), [Paysera](https://www.paysera.com/) (EU paypal similar service, also preferably) or Paypal. With Paypal if you are non EU account, I will add 2% as they charge me extra [Cross border fee](https://www.paypal.com/mt/webapps/mpp/ua/useragreement-full#tableOfFees1).*

**Please note that due to semiconductor shortage BME280 breakout boards are difficult to find (June 2021) and they are more expensive. I am currently using my own breakout where I solder the BME directly. These are a bit smaller in size than the BME breakout from China. BME280 as IC can be found occasionally in stock from DigiKey.**

### Fully assembled device with holder (excluding SGP30 VOC sensor only)
You can see the device also [in the video](https://www.youtube.com/watch?v=X75OGs2TTT8), also in [this video](https://www.youtube.com/watch?v=b2oDBgN3h1w) is shown how to complete the device with assembled PCB.




### Fully assembled excluding 3D printed holder
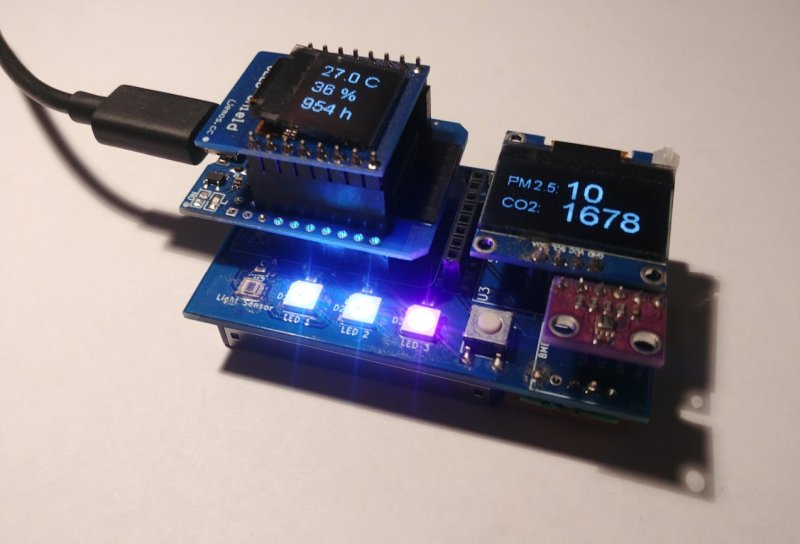
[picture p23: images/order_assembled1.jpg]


### PCB only
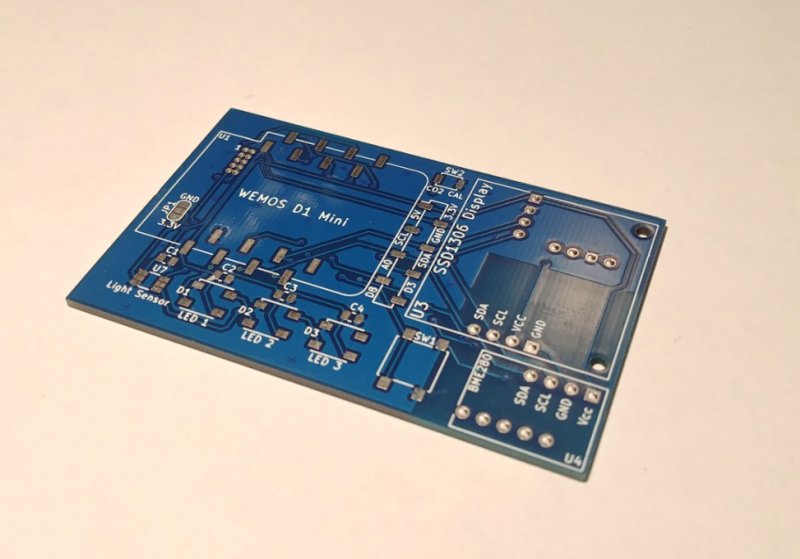
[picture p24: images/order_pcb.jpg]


### Assembled PCB
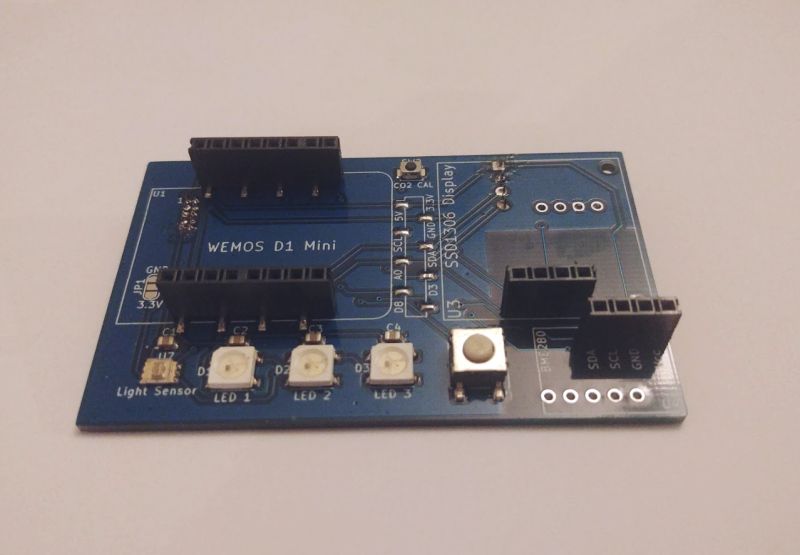
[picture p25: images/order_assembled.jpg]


### Case holder
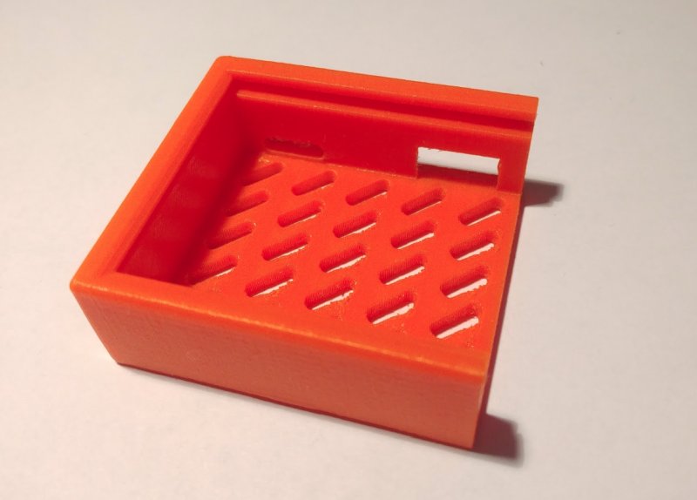
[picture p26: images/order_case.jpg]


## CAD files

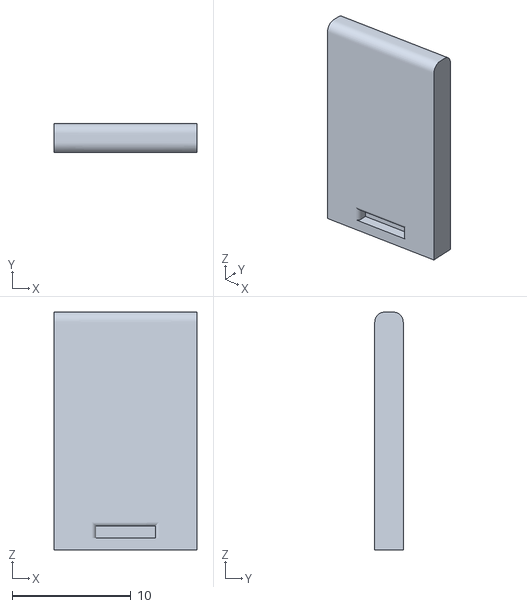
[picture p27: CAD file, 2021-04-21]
case_model/Stand_pin.stl
12.0 x 2.40 x 20.0

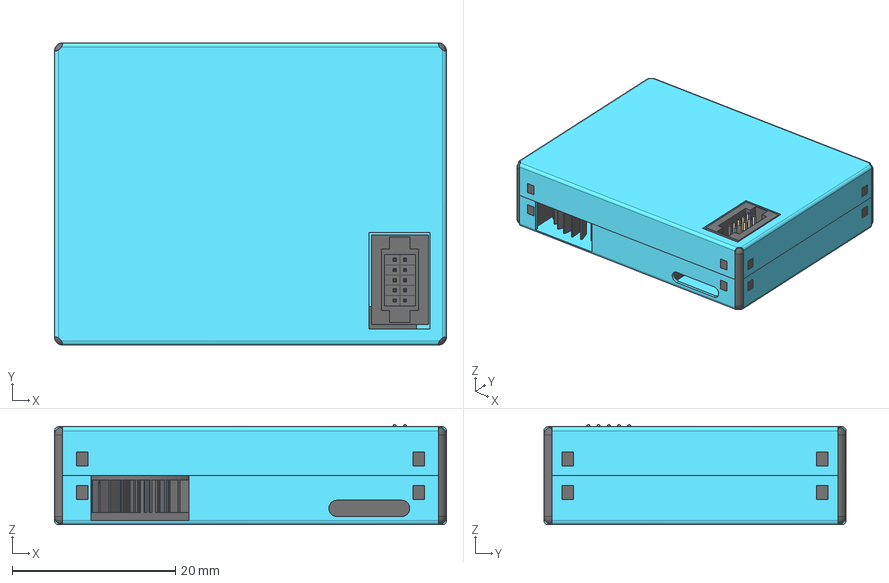
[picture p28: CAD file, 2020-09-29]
kicad/my_libs/3dmodels/pms7003.stp
48.0 x 37.0 x 12.3 mm
fan^pms7003
plastic^pms7003
metal_cover_connector
metal_cover_connector_1
1_27mm_pin_right_angle x 10
1_27mm_plastic_for_pin x 10

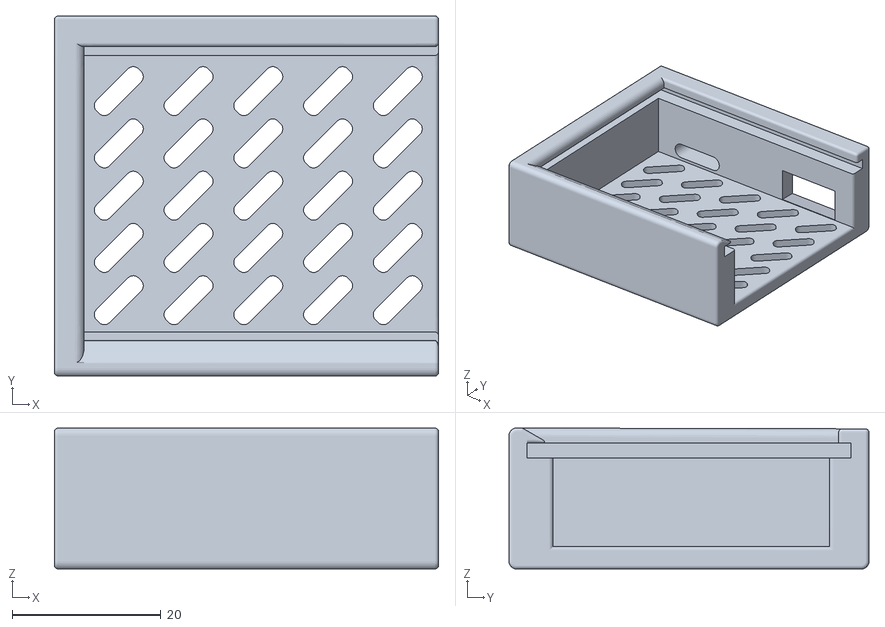
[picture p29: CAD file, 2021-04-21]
case_model/Stand_body.stl
51.7 x 48.4 x 19.0

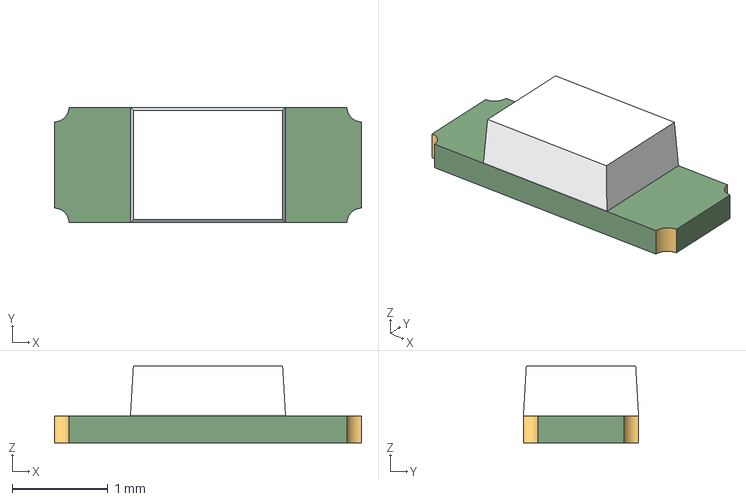
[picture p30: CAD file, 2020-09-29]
kicad/my_libs/3dmodels/RGB LED v3.step
3.20 x 1.20 x 0.8 mm

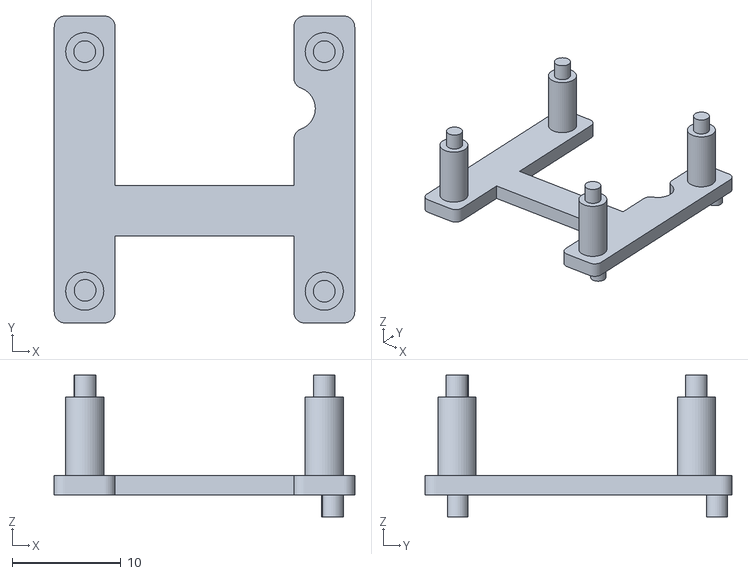
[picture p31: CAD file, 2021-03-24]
case_model/display_holder_22mm.stl
27.6 x 28.2 x 13.0

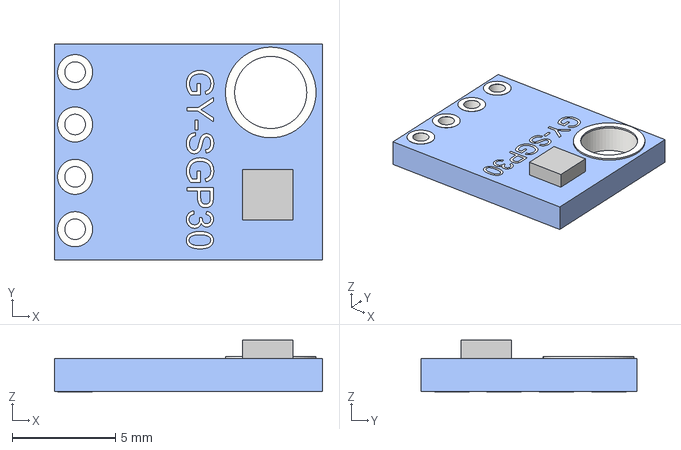
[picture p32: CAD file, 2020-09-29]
kicad/my_libs/3dmodels/sgp30_breakout v6.step
13.0 x 10.5 x 2.51 mm

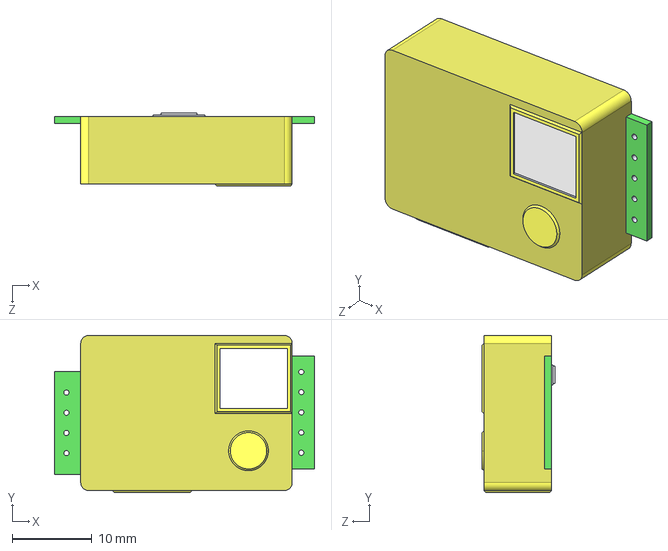
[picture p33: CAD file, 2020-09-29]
kicad/my_libs/3dmodels/MH-z19_c02_sens.STEP
32.7 x 19.8 x 9.20 mm

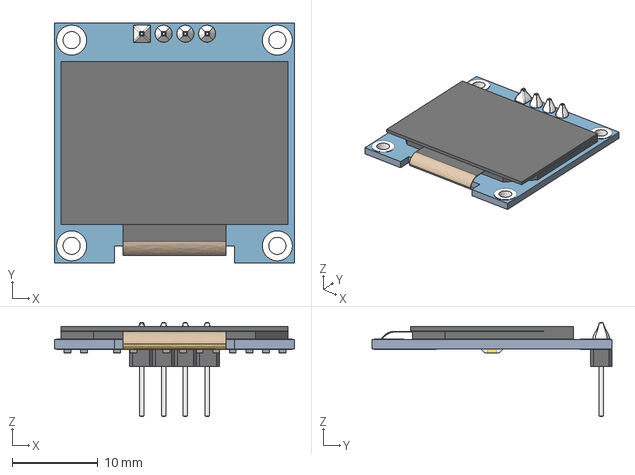
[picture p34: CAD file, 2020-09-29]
kicad/my_libs/3dmodels/0.96 OLED v3.step
28.0 x 28.0 x 11.0 mm

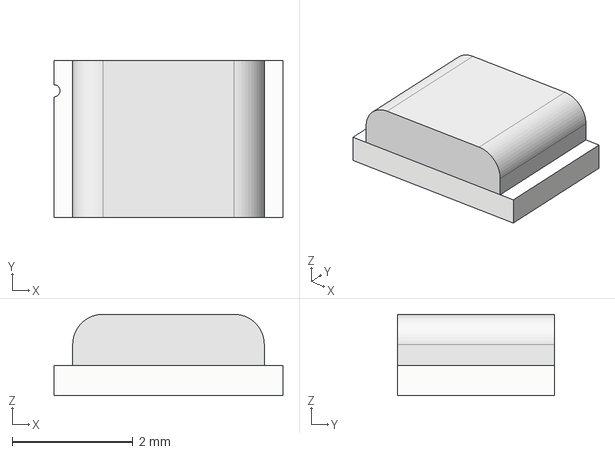
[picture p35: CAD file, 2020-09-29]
kicad/my_libs/3dmodels/TSL2561T.step
3.80 x 2.60 x 1.35 mm

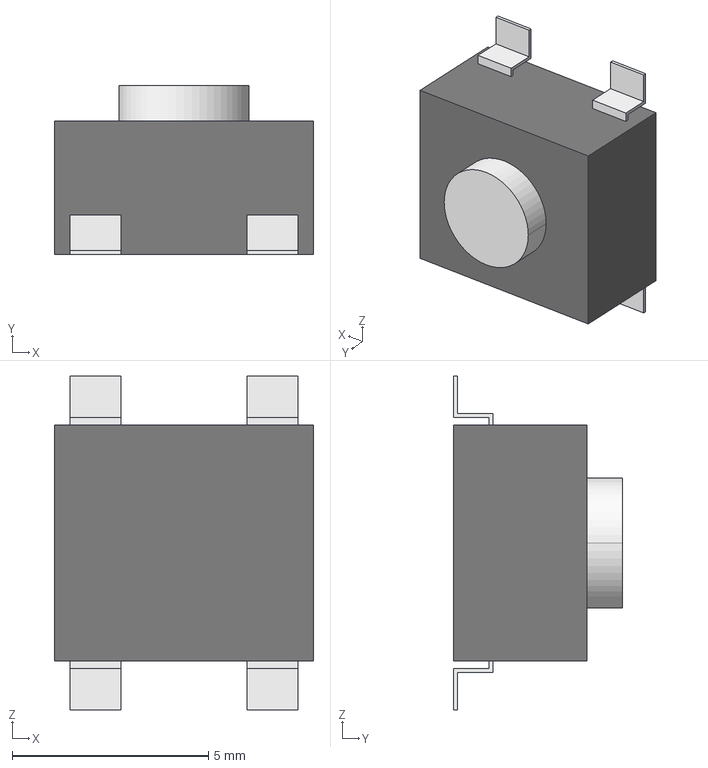
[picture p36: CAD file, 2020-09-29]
kicad/my_libs/3dmodels/b3s-1000.stp
6.60 x 4.30 x 8.50 mm

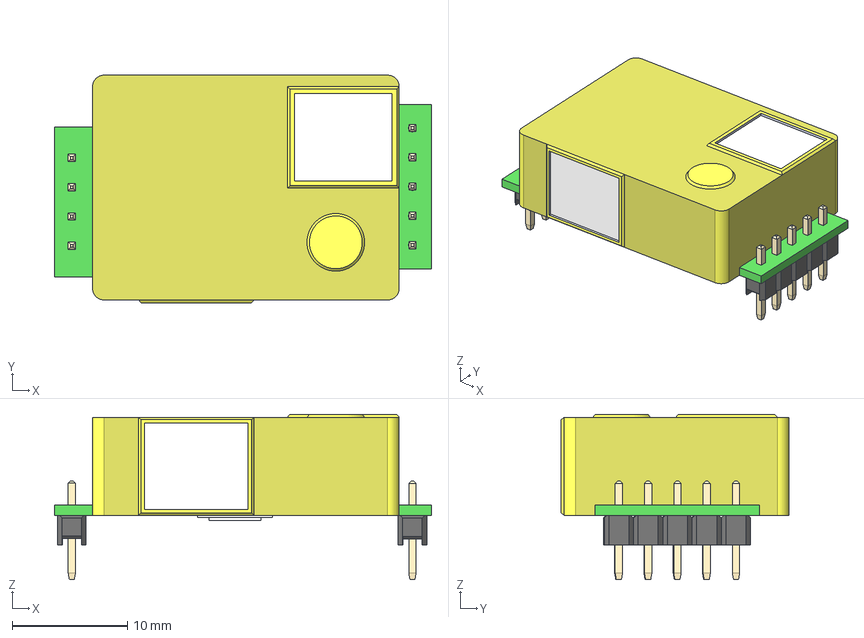
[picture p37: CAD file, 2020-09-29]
kicad/my_libs/3dmodels/MH-Z19.step
32.7 x 19.8 x 14.3 mm
MH-z19_c02_sens
1x5 Male Pin Header
1x4 Male Pin Header

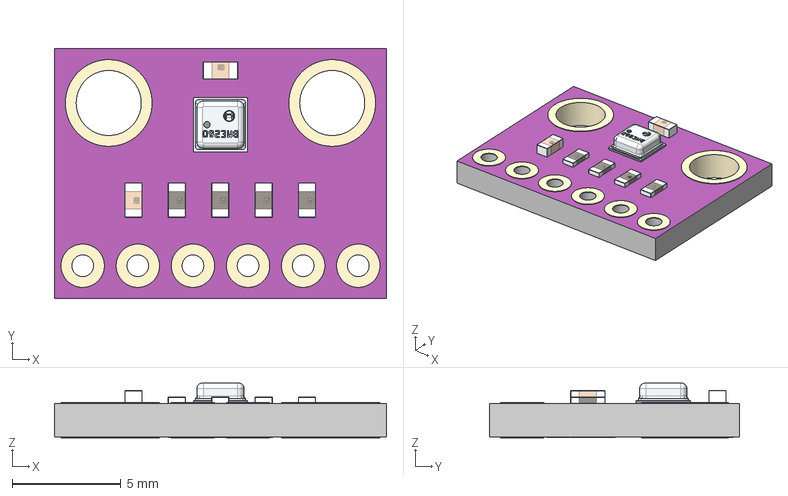
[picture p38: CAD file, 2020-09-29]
kicad/my_libs/3dmodels/P280, 6-PIN-Version v4.step
15.3 x 11.5 x 2.52 mm
Komponente1
Komponente2
Komponente3
Komponente4
Komponente5
Komponente6
Komponente7
Komponente8
Beschriftung
C0603 x 2
R0603 x 4
BME280

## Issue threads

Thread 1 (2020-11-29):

Plastic spacer missing in BOM

adebree, 2020-11-29:
Thank you so much for sharing all this information in enormous details. We are planning to build a couple of this for fun, learning and entertainment. I just noticed a plastic spacer in your video between on of the the displays and the PCB. Although technically not needed of course, can you add these to the BOM with the details of the size? Thanks!

nkitanov, 2021-01-07:
Updated the BOM with the plastic bolts I use. Spacer was some initial idea but never used it.

Closed 2021-01-07.

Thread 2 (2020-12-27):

[IDEA] Closed box

hpapagaj, 2020-12-27:
Hi,

This is a great project. It would be great to have a closed box for it (maybe for a slimmed version, without LEDs, and displays).

nkitanov, 2021-01-07:
I do not have time now to design closed box and I use all my devices with the open box, even without box. :)  If anyone wants to cornubite, please let me know to give you permissions to upload.

nkitanov, 2021-01-07:
Or just make a pull request. :)

Dinth, 2021-01-16:
+1 from me for closed box

Closed 2021-01-07.

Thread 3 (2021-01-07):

JLC PCB does not support Gerber X2

fernplant, 2021-01-07:
Hi. Fantastic project, thanks for sharing.
I went to JLCPCB to order some PCBs and this was the email they sent to me after my order:

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

adebree, 2021-01-07:
That's weird, I just received a batch of 10 PCB of the IAQ Board from
them... I used their normal online ordering tool.

This message was sent from a mobile device

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

nkitanov, 2021-01-07:
@fernplant did you used the files I provided or you regenerated them? I didn't had issues with that in the past but it was in March when I ordered the last time. I can update the files...

fernplant, 2021-01-13:
Files uploaded to them were as provided in plot.zip . Maybe was just a fluke?

Badn1nja, 2021-01-31:
I'm going to try to use the instructions here to generate the files again.

I can see they want one set of files where there is two in the files.
https://support.jlcpcb.com/article/44-how-to-export-kicad-pcb-to-gerber-files

Closed 2022-01-26.

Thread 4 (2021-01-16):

Firmware not compatible with Home Assistant ESPHome addon

Dinth, 2021-01-16:
Hi. Could you please provide a config file which would be compatible with ESPHome docker image (HA addon)?
Right now it requires: brightness.yaml include to be pasted to the main config and also is missing fonts, which im not sure how to overcome.

mikenabhan, 2021-01-17:
Brightness.yaml is linked in the firmware folder.

https://github.com/nkitanov/iaq_board/blob/master/firmware/includes/brightness.yaml

The fonts folder is also included.

https://github.com/nkitanov/iaq_board/tree/master/firmware/fonts

If you download the firmware folder so the paths match, the firmware will compile.

adebree, 2021-01-21:
For `iaq_board.yaml` to compile in the ESPHome HA Addon I had to also add a couple dependencies to the yaml:

```
  platformio_options:
    lib_deps:
      - NeoPixelBus@2.6.0
      - ArduinoJson-esphomelib@5.13.3
      - AsyncTCP-esphome@1.1.1
      - ESPAsyncWebServer-esphome@1.2.7
 ```

(The NeoPixelBus was already defined as a dep)

Dinth, 2021-01-21:
> For `iaq_board.yaml` to compile in the ESPHome HA Addon I had to also add a couple dependencies to the yaml:
>
Thanks. Im still not sure, how i can deal with fonts, HA addon doesnt allow to upload any external dependencies like fonts

adebree, 2021-01-21:
You need to manually upload the font and the brightness.yaml into the config directory of the addon. It depends a lot on how you actually are running home-assistant. But you can either SSH into HA or use a addon like Samba to get filesystem access  to it. For me that config directory is actually called `esphome` and lives within my Home Assistant data dir. The config files contains the yaml files you have created via the web interface of the ESPHome addon.

In that same dir (so next to where you have `iaq_board.yaml` and all the other ESPHome device configs) you create a `fonts` dir and upload the `Arials.ttf` file. And you create an `includes` dir where you put the `brightness.yaml` file in.

After adding the earlier mentioned additional dependencies you should be able to compile and manage the device.

Dinth, 2021-01-21:
Thank you!

Closed 2021-01-21.

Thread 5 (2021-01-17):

Question about turning the display off an the second button to reset the baseline of the voc sensor

sebastianf, 2021-01-17:
Hi,
thank you for providing your code. It is is great!

I have a similar setup and I am new to ESPHome, so I wanted to peek in your code.
I can't see where you turn off the display and where you configure the second button to reset the baseline for the voc sensor.

Can you point me in the right direction?

Thanks!

nkitanov, 2021-01-18:
Hi,

Here is the code to turn off the LEDs, it's raw C++ included with lambda. I couldn't find any other way although I am sure there is more elegant way to do it.

For the calibration of CO2 sensor (I think you are speaking for it and not VOC sensor, as VOC sensor baseline cannot be externally calibrated, it's hardcoded) here is the code, it's just a switch which executes calibration:
```
switch:
  - platform: template
    name: "CO2 Sensor Zero Calibration"
    turn_on_action:
      - mhz19.calibrate_zero: mh_sensor
      - switch.turn_off: co2_cal
    id: co2_cal
```

sebastianf, 2021-01-18:
Thanks a lot.
I found this for turning an OLED Display off
```
lambda: |-
          it.fill(COLOR_OFF);
```

nkitanov, 2021-01-18:
Ah, nice, this can be used also in the code instead of decreasing the brightness as I do it in a dumb way.

Closed 2022-01-26.

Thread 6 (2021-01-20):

Troubleshooting, all of the I2C devices give 'communication failed'

adebree, 2021-01-20:
Thanks for your awesome project, soldering it was really fun. Unfortunately I am now facing the issue none of the I2C devices can be found. I did a fully assembled board, so with the TSL2561, the BME280, both the SSD1306 OLEDs and the SGP30. In the ESPHome Debug log I get:

```
[E][bme280.sensor:146]: Communication with BME280 failed!
[E][tsl2561:044]: Communication with TSL2561 failed!
[E][ssd1306_i2c:031]: Communication with SSD1306 failed!
[E][ssd1306_i2c:031]: Communication with SSD1306 failed!
```

All the soldering looks good, have you any suggestion on how to approach this problem?

nkitanov, 2021-01-21:
Can you check if you properly soldered the receptacle or pins for the ESP board? Also another potential issue if you short circuit i2c pins bellow the TLS sensor (I done it once). It can make the whole i2c bus unusable which is your case, since none of the sensor is found.. Soldering light sensor is a bit of tricky thing and can lead to issues. I would check with a multimeter if there is any short circuit to gnd or power of the i2c pins. Or short circuit between SCL and SDA. If that is the case, just properly resolder the TLS sensor which can be a fun with regular solder iron. :)

adebree, 2021-01-21:
Your hunch was correct! It was the TLS sensor, after desoldering the I2C devices started working. Unfortunately I destroyed the TLS during desoldering.

The reason I desoldered is that I started to doubt the orientation of the TLS. I studied the pictures to find a clue how it should be oriented. Can you explain how the TLS should be oriented so when I get a replacement I won't make the same mistake again? Thanks!

nkitanov, 2021-01-21:
You can check in the datasheet how to orient it: https://github.com/nkitanov/iaq_board/blob/master/kicad/iaq_device/datasheets/TSL2561.pdf

Also using a magnifying glass is a good idea.

adebree, 2021-01-21:
ah! Got it, pin1 has a square / rectangle copper pad while the other 5 have round. Excellent, thanks!

Closed 2021-01-21.

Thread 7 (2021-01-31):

fatal error: ArduinoJson.h: No such file or directory

jamarju, 2021-01-31:
Here's the result of `esphome iaq_board.yaml run`.

Tried with:

* ESPHome v1.15.3
* ESPHome v1.17.0-dev

```
$ esphome iaq_board.yaml run
INFO Reading configuration iaq_board.yaml...
INFO Generating C++ source...
INFO Compiling app...
INFO Running:  platformio run -d iaq_board
Processing iaq_board (board: wemos_d1_mini32; framework: arduino; platform: espressif32@1.12.4)
-----------------------------------------------------------------------------------------------------------------------------------------------------------------------------------------
HARDWARE: ESP32 240MHz, 320KB RAM, 4MB Flash
PACKAGES:
 - framework-arduinoespressif32 3.10004.200129 (1.0.4)
 - tool-esptoolpy 1.20600.0 (2.6.0)
 - toolchain-xtensa32 2.50200.80 (5.2.0)
Dependency Graph
|-- <NeoPixelBus> 2.6.0
|   |-- <SPI> 1.0
|-- <DNSServer> 1.1.0
|   |-- <WiFi> 1.0
|-- <Wire> 1.0.1
|-- <Update> 1.0
|-- <WiFi> 1.0
|-- <ESPmDNS> 1.0
|   |-- <WiFi> 1.0
Compiling .pioenvs/iaq_board/src/esphome/components/api/api_connection.cpp.o
Compiling .pioenvs/iaq_board/src/esphome/components/api/api_server.cpp.o
Compiling .pioenvs/iaq_board/src/esphome/components/api/list_entities.cpp.o
Compiling .pioenvs/iaq_board/src/esphome/components/api/proto.cpp.o
In file included from src/esphome/components/light/light_color_values.h:8:0,
                 from src/esphome/components/light/light_effect.h:4,
                 from src/esphome/components/light/light_state.h:6,
                 from src/esphome/core/controller.h:11,
                 from src/esphome/components/api/util.h:5,
                 from src/esphome/components/api/list_entities.h:5,
                 from src/esphome/components/api/list_entities.cpp:1:
src/esphome/components/json/json_util.h:4:25: fatal error: ArduinoJson.h: No such file or directory

*********************************************************************
* Looking for ArduinoJson.h dependency? Check our library registry!
*
* CLI  > platformio lib search "header:ArduinoJson.h"
* Web  > https://platformio.org/lib/search?query=header:ArduinoJson.h
*
*********************************************************************

compilation terminated.
In file included from src/esphome/components/light/light_color_values.h:8:0,
                 from src/esphome/components/light/light_effect.h:4,
                 from src/esphome/components/light/light_state.h:6,
                 from src/esphome/core/controller.h:11,
                 from src/esphome/components/api/util.h:5,
                 from src/esphome/components/api/proto.cpp:2:
src/esphome/components/json/json_util.h:4:25: fatal error: ArduinoJson.h: No such file or directory

*********************************************************************
* Looking for ArduinoJson.h dependency? Check our library registry!
*
* CLI  > platformio lib search "header:ArduinoJson.h"
* Web  > https://platformio.org/lib/search?query=header:ArduinoJson.h
*
*********************************************************************

compilation terminated.
In file included from src/esphome/components/light/light_color_values.h:8:0,
                 from src/esphome/components/light/light_effect.h:4,
                 from src/esphome/components/light/light_state.h:6,
                 from src/esphome/core/controller.h:11,
                 from src/esphome/components/api/api_server.h:4,
                 from src/esphome/components/api/api_server.cpp:1:
src/esphome/components/json/json_util.h:4:25: fatal error: ArduinoJson.h: No such file or directory

*********************************************************************
* Looking for ArduinoJson.h dependency? Check our library registry!
*
* CLI  > platformio lib search "header:ArduinoJson.h"
* Web  > https://platformio.org/lib/search?query=header:ArduinoJson.h
*
*********************************************************************

compilation terminated.
*** [.pioenvs/iaq_board/src/esphome/components/api/api_server.cpp.o] Error 1
*** [.pioenvs/iaq_board/src/esphome/components/api/list_entities.cpp.o] Error 1
*** [.pioenvs/iaq_board/src/esphome/components/api/proto.cpp.o] Error 1
In file included from src/esphome/components/light/light_color_values.h:8:0,
                 from src/esphome/components/light/light_effect.h:4,
                 from src/esphome/components/light/light_state.h:6,
                 from src/esphome/core/application.h:30,
                 from src/esphome/components/api/api_connection.h:4,
                 from src/esphome/components/api/api_connection.cpp:1:
src/esphome/components/json/json_util.h:4:25: fatal error: ArduinoJson.h: No such file or directory

*********************************************************************
* Looking for ArduinoJson.h dependency? Check our library registry!
*
* CLI  > platformio lib search "header:ArduinoJson.h"
* Web  > https://platformio.org/lib/search?query=header:ArduinoJson.h
*
*********************************************************************

compilation terminated.
*** [.pioenvs/iaq_board/src/esphome/components/api/api_connection.cpp.o] Error 1
============================================================================== [FAILED] Took 2.86 seconds ==============================================================================
```

Badn1nja, 2021-01-31:
Hi thats a complication error. Please read the last of that error where platformio is offering to install the library

Badn1nja, 2021-01-31:
https://platformio.org/lib/show/64/ArduinoJson

jamarju, 2021-01-31:
Thanks for the fast response! But how should I go about installing that library?

I ran this from the `firmware` dir:

```
$ pio lib install "bblanchon/ArduinoJson"
*****************************************************************************************************************************************************************************************
Obsolete PIO Core v4.3.4 is used (previous was 5.0.4)
Please remove multiple PIO Cores from a system:
https://docs.platformio.org/page/faq.html#multiple-pio-cores-in-a-system
*****************************************************************************************************************************************************************************************
Library Storage: /Users/javi/V/DEV/esphome/iaq_board/iaq_board/.pio/libdeps/iaq_board
LibraryManager: Installing ArduinoJson
git version 2.24.3 (Apple Git-128)
Cloning into '/Users/javi/V/DEV/esphome/iaq_board/iaq_board/.pio/libdeps/iaq_board/_tmp_installing-an_ept8o-package'...
remote: Enumerating objects: 470, done.
remote: Counting objects: 100% (470/470), done.
remote: Compressing objects: 100% (413/413), done.
remote: Total 470 (delta 62), reused 160 (delta 11), pack-reused 0
Receiving objects: 100% (470/470), 309.86 KiB | 1.17 MiB/s, done.
Resolving deltas: 100% (62/62), done.
ArduinoJson @ ab90212 has been successfully installed!
```

But I'm still getting the same error:
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
jamarju, 2021-02-03:
Thanks for the hints. I think I made progress.

I added this under `platformio_options`:

```
  platformio_options:
    lib_deps:
      - NeoPixelBus@2.6.0
      - ArduinoJson-esphomelib@5.13.3
      - https://github.com/OttoWinter/AsyncTCP
      - https://github.com/OttoWinter/ESPAsyncWebServer
```

I think it now resolves all the dependencies correctly but I'm still getting a strange error at the end. It may be because I don't have the ESP32 physically connected so I'll try that later and report back.

```
$ esphome iaq_board.yaml run
INFO Reading configuration iaq_board.yaml...
INFO Generating C++ source...
INFO Compiling app...
INFO Running:  platformio run -d iaq_board
*****************************************************************************************************************************
Obsolete PIO Core v4.3.4 is used (previous was 5.0.4)
Please remove multiple PIO Cores from a system:
https://docs.platformio.org/page/faq.html#multiple-pio-cores-in-a-system
*****************************************************************************************************************************
Processing iaq_board (board: wemos_d1_mini32; framework: arduino; platform: espressif32@1.12.4)
-----------------------------------------------------------------------------------------------------------------------------
HARDWARE: ESP32 240MHz, 320KB RAM, 4MB Flash
PACKAGES:
 - framework-arduinoespressif32 3.10004.200129 (1.0.4)
 - tool-esptoolpy 1.20600.0 (2.6.0)
 - toolchain-xtensa32 2.50200.80 (5.2.0)
Dependency Graph
|-- <NeoPixelBus> 2.6.0
|   |-- <SPI> 1.0
|-- <ArduinoJson-esphomelib> 5.13.3
|-- <AsyncTCP-esphome> 1.1.1 #c18b7ca
|-- <ESPAsyncWebServer-esphome> 1.2.7 #32ab7bd
|   |-- <AsyncTCP-esphome> 1.1.1 #c18b7ca
|   |-- <FS> 1.0
|   |-- <WiFi> 1.0
|   |-- <ArduinoJson-esphomelib> 5.13.3
|-- <DNSServer> 1.1.0
|   |-- <WiFi> 1.0
|-- <Wire> 1.0.1
|-- <Update> 1.0
|-- <WiFi> 1.0
|-- <ESPmDNS> 1.0
|   |-- <WiFi> 1.0
Building .pioenvs/iaq_board/firmware.bin
Retrieving maximum program size .pioenvs/iaq_board/firmware.elf
Checking size .pioenvs/iaq_board/firmware.elf
RAM:   [=         ]  13.6% (used 44584 bytes from 327680 bytes)
Flash: [======    ]  58.4% (used 1071890 bytes from 1835008 bytes)
Traceback (most recent call last):
  File "/Users/javi/.platformio/packages/tool-esptoolpy@1.20600.0/esptool.py", line 57, in <module>
    import serial.tools.list_ports as list_ports
  File "/Users/javi/opt/miniconda3/envs/esphome/lib/python3.7/site-packages/serial/tools/list_ports.py", line 29, in <module>
    from serial.tools.list_ports_posix import comports
  File "/Users/javi/opt/miniconda3/envs/esphome/lib/python3.7/site-packages/serial/tools/list_ports_posix.py", line 31, in <module>
    from serial.tools.list_ports_osx import comports
  File "/Users/javi/opt/miniconda3/envs/esphome/lib/python3.7/site-packages/serial/tools/list_ports_osx.py", line 32, in <module>
    kIOMasterPortDefault = ctypes.c_void_p.in_dll(iokit, "kIOMasterPortDefault")
ValueError: dlsym(RTLD_DEFAULT, kIOMasterPortDefault): symbol not found
*** [.pioenvs/iaq_board/firmware.bin] Error 1
================================================ [FAILED] Took 5.05 seconds ================================================
```

nkitanov, 2021-02-04:
Keep in mind that I build this config with probably older version of esphome, I will add as ac omment later the version I use to build. However if you use `platformio_options` you can get errors on the first build. I remember that I had this and found out it's normal. Also I added this library dependance, because bug in neopixel 2.5.7 library, which is fixed in 2.6.0. Have to check if this library is updated in the latest esphome and if so, then `platformio_options` can be removed.

nkitanov, 2021-02-06:
I tested now with latest esphome 1.16.0 and it still uses neopixel 2.5.7 so lib deps cannot be removed. I updated yaml file to include comment with esphome version compatible with it.

nkitanov, 2021-02-06:
This is the issue in esphome for this: https://github.com/esphome/issues/issues/1481

jamarju, 2021-02-07:
Thanks @nkitanov !! It works now.

Now when I plug the esp32 I can't see anything on the display and the LEDs don't turn on either, but I guess that's an unrelated issue so you can close this one.

nkitanov, 2021-02-07:
Yes, this is how it works. I saw in the esphome issue someone added merge request to add neopixel 2.6.1, so it will be fixed soon,.

Closed 2022-01-26.

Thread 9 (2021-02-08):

can a MH-Z19C be used as a drop in for the MH-Z19B?

SyedAmerGilani, 2021-02-08:
The supplier in the BOM for the MH-Z19B is out of stock. It is much easier to get an MH-Z19C here in Germany from a trustier supplier then a MH-Z19B.
From the Datesheet the MH-Z19C seems to be pin compatible, but i have seen reports that say that it is more fickle with its voltage supply.
Do you have any Idea if it should work on this PCB?

nkitanov, 2021-02-08:
As I checked quickly the specs - it should be fine if the pinout is the same. Voltage requirement is 5V+/-0.1V which is fine. This sensor is powered directly by 5V from the USB conneced on the ESP board. USB voltage is in this range. Can you show some source where voltage issues are commented.

SyedAmerGilani, 2021-02-08:
See here in the lower part of the Post: https://emariete.com/en/power-from-nodemcu-wemos-mini-d1-and-arduino/
The Concern seems to be that the USB voltage can dip below 4.9V

nkitanov, 2021-02-08:
Yes, it's looking the power supply requirement is more strict than on the older versions. Just measured my device with USB from a PC and it shows 4.75V - there is no regulation of 5V rail so it have what it is provided from the USB. Theoretically this one cannot work with the new MH-Z19C, but practically it can and it have to be tested. However you will be running the senors with out of spec power supply. I would stick to the MH-Z19B for now, since this model is still available. Making 5V from 4.7V needs extra circuitry and does not worth the effort for the moment.

SyedAmerGilani, 2021-02-08:
ok i agree. Thank you !
so now to look which aliexpress dealer to trust that it does not sell fake MH-Z19B which seem to be in circulation...

Closed 2021-02-08.

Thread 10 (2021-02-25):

SGP30 - Unkown setup error

darkson95, 2021-02-25:
Hi,

First of all, I would like to thank you for the cool project. Super work! 😎

Unfortunately I have a problem with the SGP30 sensor. I built and programmed everything as you described in the repository, but when starting the device I get the following message:
```yaml
[22:24:58][C][sgp30:178]: SGP30:
[22:24:58][C][sgp30:179]:   Address: 0x58
[22:24:58][W][sgp30:195]: Unknown setup error!
[22:24:58][C][sgp30:209]:   Update Interval: 1.0s
[22:24:58][C][sgp30:210]:   eCO2 'eCO2'
[22:24:58][C][sgp30:210]:     Unit of Measurement: 'ppm'
[22:24:58][C][sgp30:210]:     Accuracy Decimals: 1
[22:24:58][C][sgp30:210]:     Icon: 'mdi:molecule-co2'
[22:24:58][C][sgp30:211]:   TVOC 'TVOC'
[22:24:58][C][sgp30:211]:     Unit of Measurement: 'ppb'
[22:24:58][C][sgp30:211]:     Accuracy Decimals: 1
[22:24:58][C][sgp30:211]:     Icon: 'mdi:radiator'
[22:24:58][C][sgp30:213]:   Compensation:
[22:24:58][C][sgp30:214]:     Temperature Source: 'Temperature'
[22:24:58][C][sgp30:214]:       Unit of Measurement: '°C'
[22:24:58][C][sgp30:214]:       Accuracy Decimals: 1
[22:24:58][C][sgp30:214]:       Icon: 'mdi:thermometer'
[22:24:58][C][sgp30:215]:     Humidity Source: 'Humidity'
[22:24:58][C][sgp30:215]:       Unit of Measurement: '%'
[22:24:58][C][sgp30:215]:       Accuracy Decimals: 1
[22:24:58][C][sgp30:215]:       Icon: 'mdi:water-percent'
```

The first thing I thought was that the sensor is broken and I tried a NodeMCU (ESP8266) and set it up in ESPHome (+ Home Assistant). _There everything worked and I got legitimate values back, so the sensor can not be broken._
I also tried to connect the sensor to the PCB with the receptacle in the middle of the board, but I got the same error.

This is the relevant configuration for the SGP30:
```yaml
i2c:
  scl: GPIO22
  sda: GPIO21
  frequency: 100kHz

sensor:
  - platform: sgp30
    address: 0x58
    eco2:
      name: "eCO2"
      accuracy_decimals: 1
      id: eco2
    tvoc:
      name: "TVOC"
      accuracy_decimals: 1
      id: tvoc
    update_interval: 1s
    baseline:
      eco2_baseline: 0x92B7
      tvoc_baseline: 0x935A
    compensation:
      temperature_source: temp
      humidity_source: hum
```

Do you guys have any idea what the problem could be?

nkitanov, 2021-02-25:
Hi,

I have similar error with my second SGP30 from Aliexpress and decided that is broken so I  throw it in the bin. Then yesterday it was reported to me for a simliar issue which can be fixed by removing some of the orther i2c devices like bme280 sensor - then magically sgp30 sensor is working. The setup there is all things on i2c - 2 displays, bme280 and sgp30.

I have a hypothesys that the 4 paralel pullup resistors are dropping too much the voltage state on the bus. Schematic of the sgp30 brearout is similar to this: https://cdn-learn.adafruit.com/assets/assets/000/097/500/original/adafruit_products_SGP30_sch.png?1607379580

If you are using all 4 devices on the i2c, can you try removing any of it to see if sgp30 is working. Unfortunatelly I don't have anymore my problematic sgp30 to measure the bus with the scope and see it that can cause it. If it's working then - easy try is to remove some of the pullups on any of the other i2c devices. They normally are 10 kOhm and 4 in paralel should not cause issues but who know...

darkson95, 2021-02-25:
Thank you for the quick response at this late hour.

I have removed all displays and also commented out in the code. The sensor then returned me values. So I first put the big display back on to check if it still works. Then the small display.

For whatever reason all sensors and all displays now work as I wanted them to. Thanks for the support! 🥇

nkitanov, 2021-02-25:
OK. I will reopen that, as I thing have to check it when I get back some new sgp30 sensors.  :)

darkson95, 2021-03-10:
Hi again! :)

Today the ambientlight sensor TSL 2561 arrived and I have now installed all the parts as you described in the project. Unfortunately, I have the problem that the SGP30 can not start again, so I have removed all displays that at least data can be captured.

I thought I'd share this with you if you still have the issue open. 🙂

nkitanov, 2021-03-10:
Hi. I do not havy any sgp30 sensors right now, and when I reveive a few in 2 weeks will do verification. Probably removing the pullup resistors on the sgp30 board will solve it.

nkitanov, 2021-03-14:
Ok, I got a few SGP30 breakout boards from Aliexpress. As expected the first one I tested gives the same issues. Then I hooked up the osciloscope to check the i2c levels but it's not a problem, this board have 10k pullups so no issues there. SGP30 is using 1,8V power supply and on this breakout it is having the chinese LDO regulator [SC6206B-65K5](https://lcsc.com/product-detail/Dropout-Regulators-LDO_Shenzhen-Fuman-Elec-SC6206B-65K5_C88294.html). Anyway I noticed that the regulated voltage after the LDO is having very unusual 440mVp-p noise, which on my working SGP30 board is not there. Here is a snap from the osciloscope:

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

Then I measured the output capacitor after the LDO regulator and it was aroung 2uF, while on the working board it was 10 uF, although even 2uF should work. Then I removed the output capacitor and the board started working.

My not very detailed conclusion, since I am not electronics expert: These chinese breakout board are pretty bad in quality. Apparently they soldered what they have. Also I guess some of these capacitors are faulty. I got a few other boards and some of them have the same issue, although even with the noise some were working but now all. There was one completely dead probably because of faulty mosfet array (the switch circuit to drop i2c signals from 3.3V to 1.8V). I have a friend who found on his SGP30 board short circuit in the LDO regulator pins. So it's a gambling if this thing will work.

What is the solution if your SGP30 sensor experience issues (either completely blocking i2c like not having any displays, etc. or just not receiving TVOC data)? Just unsolder this capacitor and if you have 10 uF SMD capacitor put it there or just leave it without (still working and noise not there anymore):

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

If that is not solving the issue, then there is somethinge else with these poor boards. You can measure the LDO if it's providing 1.8V, check the i2c after the mosfet array (having proper 1.8V high levels), etc... Check for short circuits, etc. I might change the design to use more simplistic SGP30 boards (without the requlator) but then the 1.8V regulation and drop on i2c signals needs to be utilized on my board. And probably not a good idea - it increases the complexity and TVOC is not so important anyway (at least for me).

kokanov-del, 2021-03-29:
Hi!
I also thank you for the compact project!
The SGP30 module was also a problem for me.
After removing the BME280, SGP30 - did it work !?
The treatment offered by you restored the functionality of the SGP30 module !!
I later found the following.
Without a 10μf capacitor, the SGP30 sensor module is not sensitive to VOS and eCO2.
With 10μf capacitor, works normally.
Thanks for the support!

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

donnie-darko, 2021-04-13:
Just a quick head-up:
maybe this one is a better SGP30 Breakout board with quality components:
https://shop.pimoroni.com/products/sgp30-air-quality-sensor-breakout

Anyway, thanks for this cool project! I find nowhere else an easy, low-cost DIY air quality monitor like this one

nkitanov, 2021-04-13:
This is better quality for sure. The only problem here is that this board is not fitting the layout on the iaq board. You need to connect it in a weird way or with floating cables.

donnie-darko, 2021-04-14:
Or maybe consider this breakout board when designing the next version of the PCB layout 😸

beicnet, 2021-09-30:
@nkitanov I like your project and I wanted to use the same SGP30 from Ali, so, today I got two of them, but unfortunately neither of them are working with other I2C devices attached.

The SGP30 (GY-SGP) Sensor is working without any issue if there is no other I2C devices attached to the bus.

If I remove the capacitor what you suggested, the sensor module will not work as expected (will return wrong Device ID and Values too).

Did you got to some other conclusion over the time past by?

nkitanov, 2021-09-30:
@beicnet I don't know. The only thing I can suggest - try soldering 0.1uF bypass capacitor on the place of the removed one and try again.

beicnet, 2021-09-30:
@nkitanov I made a quick test on UNO with this SGP30 sensor board:

It can work only with two other i2c devices beside, if you add a third device it will stop and block the whole i2c bus.

What do you think?

beicnet, 2021-09-30:
@nkitanov It was all pull-up resistor caused issue (fixed).

mwolter805, 2022-01-01:
Build IAQ-Board with SGP30 ordered December 8th 2021 from this [link](https://www.aliexpress.com/item/4000004614708.html) and did not have any issues.

nkitanov, 2022-01-07:
> Built an IAQ-Board with an SGP30 ordered December 8th, 2021 from this [link](https://www.aliexpress.com/item/4000004614708.html) and did not have any issues with an BME280 connected.

Sometimes it works, I guess. :)

divB0, 2023-02-25:
I am having a similar issue. SGP30 with BME280 doesn't work. @beicnet how did you fix the issue?

olmelabs, 2024-03-01:
I had the same issue when powering SGP30 from AliExpress from 5v. As an experiment, I put it to 3.3v pin and magically it started working. Documentation states it is either 3.3 or 5v, but seems not for this guy.

mwolter805, 2024-03-02:
Could be a power supply issue. I'm using a different dev board, [QUINLED-ESP32 ABE](https://quinled.info/quinled-esp32/) where the 5v is powered from PoE and has stronger 3v3 than typical.

Closed 2022-01-07.

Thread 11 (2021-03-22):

Second Display linked in BOM does not work correctly

SyedAmerGilani, 2021-03-22:
I bought the exact linked display. But i took the v2 Version with the Buttons on the Ali Express site.
The Problem is that it displays the same contents as the first display, regardless which address is configured.

Which looks like this:
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

The Display looks like this:
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

I even tried removing the  first display completely from the code which just had the effect that none of the displays showed anything.
My current assumption is that those displays are simply bad, but maybe somebody has an input.

Funny thing about the first display is that mine is configurable on the back between 0x78 and 0x7A but it still works with the default addresses.

nkitanov, 2021-03-22:
It is simple - both displays have the same i2c address. This particular display have a tiny connection between the two pads (I got that info from a friend, never had these displays). Just cut it with a razor and it should work:

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

SyedAmerGilani, 2021-03-23:
oh :man_facepalming:
what i thought was what they meant is that those pads should be soldered or unsoldered...
just measured them, yeah they are connected even then unsoldered.
thanks for the input.

nkitanov, 2021-03-23:
I think I also have one of these somewhere and maybe year ago had the same issue. :) These Chinese parts are like a box of chocolates. You never know what you're gonna get. :)

Closed 2021-03-23.

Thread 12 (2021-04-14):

Questions about this device

AalianKhan, 2021-04-14:
Hello,
I am building a device for room presence detection and I was wondering if this type of device might be what I need for the job.
From asking around I found out that humans produce lots of carbon dioxide when breathing so it can become a viable metric for presence detection.
So can you or someone who built this device can tell me the carbon levels when there is a human present and when there is no one. I am mainly interested in how big the difference is.
Also how much time does it take for the carbon levels to be normal/stable.

And about the carbon dioxide sensors you said that the sgp30 is more or less inaccurate compared to the dedicated sensor so I was wondering how inaccurate is it?
Thank you!

nkitanov, 2021-04-14:
Hi. Why you want to detect presense with CO2 senor? You can use more traditional approach with PIR sensors. You can detect eventually presense with CO2 senor but it's very odd - it will be slow to react, it depends on the number of people and size of the room, also internal ventilation, etc. It's much better to use PIR or bluetooth tokens and similar more traditional approach.

AalianKhan, 2021-04-14:
I will use PIR sensors for detecting the the motion but when the person is not moving, detecting CO2 may be a good way to detect if someone is present.

Also I am looking for a way to detect people without devices that people have to carry for example when guests come over and such.

nkitanov, 2021-04-15:
You can but it's really a side effect and dependant of a lot of things. For example in a not ventilated room the CO2 will increase when somebody is there but if you ventilate it - it drops. I would rather use IR long range sensor to detect that there is unmoving person. It's more complicated but much more stable.

AalianKhan, 2021-04-15:
I see, thank you for your advice. I think I will start looking into esp32
cams and object detection.

On Thu., Apr. 15, 2021, 4:05 a.m. Nikolay Kitanov, ***@***.***>
wrote:

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

Closed 2022-01-26.

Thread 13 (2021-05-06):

PMSX003 Sleep mode

jcastro, 2021-05-06:
Hello!
Amazing work on the sensor. I've got already all the components currently working on a protoboard.

I've got a question related the PMSX003 (I have the PMS7003). I noticed that when sleeping the fan is audible for me so I was wondering if there's a way to put it into sleep mode and wake it up each XX minutes to take a reading. That would also hopefully make the sensor life longer.

I've checked the yaml in the repo but it seems there's nothing like that included.

Thanks for any info and sharing this with us!

nkitanov, 2021-05-06:
Hi,

Actually it's there, but commented: https://github.com/nkitanov/iaq_board/blob/b1ebee55ac306f0fe6a9aa39c6b358623c784f9c/firmware/iaq_board.yaml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

There is a switch pms_set which is always on, but you can uncomment this setting and tweak it. If you uncomment it it will run for 10s each 60s. However keep in mind that the fan needs to work sometime in order to get correct data. I think 10s is enough. But I don't use it on any of my devices. You can tweak it and rebuild the binary if you want to turn it on and off. Also by having this pms_set switch you can turn it on demand by the home assistant (like only when you need to know the PM values).

P.S. you have very good hearing, or the PMS sensor is faulty. :) I had a device 40cm from my head and I do not hear it during the night.

jcastro, 2021-06-16:
Ohhh nice! Will give it a try. Thanks so much!

jcastro, 2021-06-16:
Alright, I got it working. I don't have the full device just a few sensors connected through dupont cables on the breakout board. Looking at the schematics there's a pms_set that also needs to be connected but I guess in that case I will have to use the other connectors and not the dupont! :(

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

Closed 2021-06-16.

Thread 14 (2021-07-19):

Import files into EasyEDA

jcastro, 2021-07-19:
Hi!
I'm trying to import the Kicad files into EasyEDA but I'm getting an error. I'm not sure if it's the way Kicad export the files or the other way around. Is there any other options for exporting on kicad. Looks like EasyEDA supports these
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

nkitanov, 2021-07-19:
Hi,

Unfortunatelly I do not have any idea about EasyEDA.

jcastro, 2021-07-19:
Thanks!

Closed 2021-07-19.

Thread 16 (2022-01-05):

Redesign board for QuinLED-ESP32 Ethernet

mwolter805, 2022-01-05:
Hello,
Thank you for the great project! I built an IAQ-Board and it works well. The only issues experienced are the typical WiFi issues. To help with these WiFi issues I am interested in designing a new PCB to work with the [QuinLED-ESP32](https://quinled.info/quinled-esp32/) boards. Specifically, the [ethernet](https://quinled.info/quinled-esp32-ethernet/) model but it should work for the other QuinLED boards too. Also, since the QuinLED boards share the same pinout, it will work with the WeMos D1 Mini ESP32 as well.

Unfortunately, the Ethernet module of the QuinLED board requires many of the same pins as your PCB layout, and the serial ports, i2c, and the button will need to be moved.

I2C: GPIO21 -> GPIO13 and GPIO22 -> GPIO14
PMS7003 Serial: GPIO1 -> GPIO15
MH-Z19 Serial: GPIO18 -> GPIO1 and GPIO19 -> GPIO3
Button: GPIO23 -> GPIO32
PMS7003_SET: GPIO26 -> GPIO33

**Questions**
- Do you see an issue with using the pins above? I've tried to avoid input only as well as bootstrap pins.
- In the readme, you also mention changing the pin of one of the dust sensors. Can you provide more info?

nkitanov, 2022-01-08:
Hi,

In order to move the pins a new PCB is needed. I was planning to do that if I redisign th PCB (at least to free the serial port as it's now shared with MH sensor - the reason is that this PCB was initially designed for ESP8266) but never done this and currently I do not plan any changes to this PCB. Eventually if I find time I may rediesign completely new board but it will be with integrated esp32. But for this board there will be no change. I published kicad files, so you can try to redesign yourself for your needs.

Best regards
Nikolay

Closed 2022-01-26.

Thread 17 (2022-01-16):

PCB pin socket for MH-Z19 CO2 sensor

akwan, 2022-01-16:
Hi!

Saw your installation video - considering the CO2 sensor is the most expensive part and the B version seems more difficult to get, along with several different versions (and bad clones)-
- MH-Z19B
- MH-Z19C
- MH-Z19D
- MH-Z1311A

Was thinking of revisiting the ability to make this piece removable (in case I need to swap sensors due to fake or something else - even some Z19C versions are being rebadged as Z19B). Making it removable will most likely alter the overall thickness and height of the device from the pcb. I've also been looking into PCB pin socket/receptacles to see if it's possible to minimize the height difference.

Thanks for this project!

nkitanov, 2022-03-08:
Hi. I have the same idea but in case I completely redesign the board. My idea was to use surface-mounted receptacles with a bottom insert. Of course, this needs a new PCB. I guess you can also use some female receptacles now but it will make the whole assembly a bit thicker.

Regarding the sensors - recently I was using the C version and it's good. It has the same pinout as B. For the rest, I don't know. In order to be sure you have the original buy from the official Winsen store in aliexpress. These are original sensors for sure. Otherwise, with the other random sellers, you risk getting the counterfeit item as I got once a batch of 5 pieces.

This is the official store: https://winsen.aliexpress.com/store/911125035

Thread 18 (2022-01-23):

Replacement for TSL 2561?

htilly, 2022-01-23:
Hi!

First off, thanks for a great project. Im waiting for all my parts to arrive to I can go ahead and assemble it !
However, it seems quite hard to get the TSL 2561..  Do you have any suggestion of a "drop in replacement" for this part?

/Tilly

nkitanov, 2022-03-08:
Hi. Since I froze this project I never looked for a drop in replacement. Still have some 20 pcs. I know TLS2561 is not available anymore although it can be found in Aliexpress. If you find any direct replacement please let me know. I was looking at https://www.digikey.bg/en/products/detail/ams/TSL25911FN/4162547 but it have different pins, so new PCB will be needed. I guess the best option is just to buy from Aliexpress as long as there is some stock.

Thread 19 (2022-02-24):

Turn off Wemos D1 ESP32 onboard led

ecoenjaerts, 2022-02-24:
I have everything set up and working. Good work on the displays and led turning off when it gets dark. The Wemos ESP32 onboard led however stays on. Is there a way to turn this off at the same time?

nkitanov, 2022-03-08:
It's not possible to turn it off. It's directly wired to the power of the USB. I just unsolder these or use a knife to remove them. No other option.

Closed 2022-03-08.

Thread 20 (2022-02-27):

No reading from PMS7003

DrBlokmeister, 2022-02-27:
Hey! First of all thanks for your work on this project. I really appreciate it. It's the first time I ordered a custom PCB and I hope it will bring me to making more custom devices.

I have ordered your PCB, with the D1 mini ESP32, the MH-Z19 and PMS7003. Other sensors/components are still on their way.

Therefore I use a limited part of your config:
```YAML
uart:
  - rx_pin: GPIO1
    baud_rate: 9600
    id: pms

  - rx_pin: GPIO18
    tx_pin: GPIO19
    baud_rate: 9600
    id: mh

sensor:
    - platform: pmsx003
      type: PMSX003
      uart_id: pms
      pm_1_0:
        name: "PM 1 Concentration"
        id: pm1
      pm_2_5:
        name: "PM 2.5 Concentration"
        id: pm2_5
      pm_10_0:
        name: "PM 10 Concentration"
        id: pm10

    - platform: mhz19
      co2:
        name: "CO2"
        id: co2
      temperature:
        name: "MH-Z19 Temperature"
      update_interval: 10s
      automatic_baseline_calibration: false
      uart_id: mh
      id: mh_sensor

switch:
  - platform: gpio
    name: "PMS7003_SET"
    pin:
      number: GPIO26
      mode: OUTPUT
    restore_mode: ALWAYS_ON
    id: pms_set
```

The readings from the CO2 sensor are just fine and roughly what I expect. However, I get no reading from the PMS7003.

Some observations:

- The fan of the PMS7003 is running, so I assume that 5V and GND are connected correctly
- Using a multimeter, I measured:
  - 0.4 Ohm between the two 5V pins (of PCB header)
  - 0.4 Ohm between the two GND pins (of PCB header)
  - open loop between 5V and GND pins (of PCB header)
  - open loop or >MOhm between other pin combinations (of PCB header)
  - 0.4 Ohm between GPIO1 on Wemos D1 and pin9 of PCB header
From this I conclude that galvanically, the connections should be fine.

I've thought about my PMS7003 being faulty, but I have no way to double check as I have no 1.25 mm pitch headers/converter cables.

I read somewhere online about pulling up the set pin. Is this required for this board?

Is there something else I should check before ordering a new sensor?

DrBlokmeister, 2022-02-27:
I got it working. I wedged a 10 kOhm resistor between 3.3V and GPIO18 and changed the switch configuration to pin18:

```YAML
switch:
  - platform: gpio
    name: "PMS7003_SET"
    pin:
      number: GPIO18
      mode: OUTPUT
    restore_mode: ALWAYS_ON
    id: pms_set
```

I think your standard YAML file is wrong, as you need to use GPIO18 and not GPIO26.

Otherwise this issue can be closed.

flaviut, 2022-04-06:
Would you mind re-opening this for visibility? I had to do this too, and things now work great.

DrBlokmeister, 2022-04-06:
Reopened as the default yaml file is wrong.

nkitanov, 2024-01-23:
Is that still valid? Sorry, but I do not work actively anymore on this project and can't help much. However, if pins are wrong, then the ESP32 board is different. Not sure if there is any changes with the new ESP32 boards. I remember that RX and TX pins are crossed according to the documentation of the board, even noted that in the documentation:

> In the description of [WeMos_D1_mini_ESP32](https://www.aliexpress.com/item/4000880936043.html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,searchweb201602_,searchweb201603_) the pins for UART0 are crossed (TX is where RX is shown). It's easy to fix as you can select those pins but if you carefully check the pins you might wonder why is that.

Badn1nja, 2024-01-24:
Mine is working on GPIO26
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

What boards are you using? Maybe it needs another yaml/comment added to yaml just to help anyone in the future with the same board? For reference; I am using MH-ET LIVE esp32 minikit v2.0 with the current yaml

invinciberry, 2025-09-28:
@Badn1nja I tried your fork but no luck. Mind providing a link to where you got your esp32? I suspect it's the board that I bought is different.

invinciberry, 2025-09-29:
@Badn1nja I tried a few more things, and it turns out my issue has something to do with ESPhome updates. Flashing the compiled pin file from your fork fixes my issue entirely, but compiling the firmware from the latest ESPhome version will result in no reading from the PMS sensor.

Do you mind telling me the version you used when compiling the bin file? I can try digging through the change log and try to figure out where the breaking change is.

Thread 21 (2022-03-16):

Through board instead of smd

tyme2tb, 2022-03-16:
I was wondering how hard it would be to change the design to have through board holes for the D1 Mini, instead of SMD pads? I have not played with trying to design a PCB before.

Thanks

tyme2tb, 2022-03-17:
closing because I figured it out

nkitanov, 2022-03-17:
Of course PCB can be modified but if you make through hole connection then yoou can't install beneath it the PMS sensor. Then the PCB will be overall too big.

Closed 2022-03-17.

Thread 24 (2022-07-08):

Error in compiling firmware

arjendewolf, 2022-07-08:
I just completed building two of the iaq boards and they both are connected to wifi and work (I love them!). I can integrate them both in Home Assistant independently. However, when I want to integrate them both, it only shows one working device. Since i figured HA has no way to differentiate one from another, I wanted to change the name in the .yaml file. Unfortunately, when compiling I get the error:

Failed config

light.neopixelbus: [source /config/esphome/arjen.yaml:591]

  'variant' is a required option for [light.neopixelbus].
  platform: neopixelbus
  num_leds: 3
  pin: GPIO16
  name: RGB strip
  id: rgb_led
  default_transition_length: 0s

Does someone have an idea how to solve this? Or an alternative approach to solve my initial problem?
Many thanks!

evilbulgarian, 2022-07-08:
The variant is:
variant: 800KBPS

I had to do this to get them to show up independently in HA using mqtt:

mqtt:
  broker: x.x.x.x
  discovery: true
  discovery_unique_id_generator: mac

Otherwise i think changing the name and using HA api should work just fine.

arjendewolf, 2022-07-08:
>

Thanks for your quick reply and help! Much appreciated. I am not sure where to put the "Variant: 800KBPS" in the yaml file.
Any thoughts on that?
If this should not work, i'll try to dive into mqtt, but that's kind of new to me.

arjendewolf, 2022-07-08:
Thank you! I found out where to put the "variant: 800KBPS" line. Now it starts to compile and it makes lots of progress. Then the following error occurs:

In file included from /data/iaq_boardnieuw/.piolibdeps/iaq_boardnieuw/NeoPixelBus/src/internal/DotStarGenericMethod.h:126:0,
                 from /data/iaq_boardnieuw/.piolibdeps/iaq_boardnieuw/NeoPixelBus/src/NeoPixelBus.h:83,
                 from /data/iaq_boardnieuw/.piolibdeps/iaq_boardnieuw/NeoPixelBus/src/internal/NeoGamma.cpp:28:
/data/iaq_boardnieuw/.piolibdeps/iaq_boardnieuw/NeoPixelBus/src/internal/TwoWireSpiImple.h:29:17: fatal error: SPI.h: No such file or directory

*************************************************************
* Looking for SPI.h dependency? Check our library registry!
*
* CLI  > platformio lib search "header:SPI.h"
* Web  > https://registry.platformio.org/search?q=header:SPI.h
*
*************************************************************

compilation terminated.
*** [/data/iaq_boardnieuw/.pioenvs/iaq_boardnieuw/lib7e9/NeoPixelBus/internal/NeoGamma.cpp.o] Error 1
In file included from /data/iaq_boardnieuw/.piolibdeps/iaq_boardnieuw/NeoPixelBus/src/internal/DotStarGenericMethod.h:126:0,
                 from /data/iaq_boardnieuw/.piolibdeps/iaq_boardnieuw/NeoPixelBus/src/NeoPixelBus.h:83,
                 from /data/iaq_boardnieuw/.piolibdeps/iaq_boardnieuw/NeoPixelBus/src/internal/NeoPixelAnimator.cpp:27:
/data/iaq_boardnieuw/.piolibdeps/iaq_boardnieuw/NeoPixelBus/src/internal/TwoWireSpiImple.h:29:17: fatal error: SPI.h: No such file or directory

*************************************************************
* Looking for SPI.h dependency? Check our library registry!
*
* CLI  > platformio lib search "header:SPI.h"
* Web  > https://registry.platformio.org/search?q=header:SPI.h
*
*************************************************************

compilation terminated.
*** [/data/iaq_boardnieuw/.pioenvs/iaq_boardnieuw/lib7e9/NeoPixelBus/internal/NeoPixelAnimator.cpp.o] Error 1

A bit strange because I am following the precise steps from previous solved issue in this GIT.
Any thoughts?

arjendewolf, 2022-07-08:
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

I was able to fix it by removing the entire "platformio options" section.
Now both boards show up in HA as different devices, but some sensors are not available. When I connect them separately, all sensors work. I'll try some changes in the yaml file and see if that works. Otherwise, your mqtt option is perhaps the most viable one.

arjendewolf, 2022-07-08:
I got it working! Changed the names of the sensors, and now the devices are seperated in HA. So happy now, thanks for your help!

Closed 2022-07-08.

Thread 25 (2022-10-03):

YAML doesnt compile on new ESPHome - Neopixel variant not defined

Dinth, 2022-10-03:
Hi. I cannot compile it using the latest ESPHome, because im getting Neopixel error:
```
INFO Reading configuration /config/esphome/iaq-privateoffice.yaml...
WARNING 'iaq_privateoffice': Using the '_' (underscore) character in the hostname is discouraged as it can cause problems with some DHCP and local name services. For more information, see https://esphome.io/guides/faq.html#why-shouldn-t-i-use-underscores-in-my-device-name
Failed config

light.neopixelbus: [source /config/esphome/iaq-privateoffice.yaml:587]

  'variant' is a required option for [light.neopixelbus].
  platform: neopixelbus
  num_leds: 3
  pin: GPIO16
  name: RGB strip
  id: rgb_led
  default_transition_length: 0s
```

Closed 2023-10-17.

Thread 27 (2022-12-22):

Firmware doesnt compile on 2022.12.X ESPHome - linking problem

Dinth, 2022-12-22:
Hi. After the update to 2022.12 the firmware stopped compiling.
```
Compiling /data/iaq-kitchen/.pioenvs/iaq-kitchen/FrameworkArduino/esp32-hal-uart.c.o
Compiling /data/iaq-kitchen/.pioenvs/iaq-kitchen/FrameworkArduino/firmware_msc_fat.c.o
Compiling /data/iaq-kitchen/.pioenvs/iaq-kitchen/FrameworkArduino/libb64/cdecode.c.o
Compiling /data/iaq-kitchen/.pioenvs/iaq-kitchen/FrameworkArduino/libb64/cencode.c.o
Compiling /data/iaq-kitchen/.pioenvs/iaq-kitchen/FrameworkArduino/main.cpp.o
Compiling /data/iaq-kitchen/.pioenvs/iaq-kitchen/FrameworkArduino/stdlib_noniso.c.o
Compiling /data/iaq-kitchen/.pioenvs/iaq-kitchen/FrameworkArduino/wiring_pulse.c.o
Compiling /data/iaq-kitchen/.pioenvs/iaq-kitchen/FrameworkArduino/wiring_shift.c.o
Archiving /data/iaq-kitchen/.pioenvs/iaq-kitchen/libFrameworkArduino.a
Linking /data/iaq-kitchen/.pioenvs/iaq-kitchen/firmware.elf
/data/cache/platformio/packages/toolchain-xtensa-esp32/bin/../lib/gcc/xtensa-esp32-elf/8.4.0/../../../../xtensa-esp32-elf/bin/ld: /data/cache/platformio/packages/framework-arduinoespressif32/tools/sdk/esp32/lib/libvfs.a(vfs.c.obj): in function `esp_vfs_utime':
/Users/ficeto/Desktop/ESP32/ESP32S2/esp-idf-public/components/vfs/vfs.c:585: multiple definition of `utime'; /data/iaq-kitchen/.pioenvs/iaq-kitchen/src/main.cpp.o:/config/esphome/.esphome/build/iaq-kitchen/src/main.cpp:68: first defined here
collect2: error: ld returned 1 exit status
*** [/data/iaq-kitchen/.pioenvs/iaq-kitchen/firmware.elf] Error 1
========================= [FAILED] Took 59.34 seconds ==================
```

fraserp, 2022-12-28:
Experiencing the same, have cleaned the build files to no avail.

paveldn, 2022-12-28:
Change line 427 in iaq_board.yaml:

```
    - platform: uptime
      name: Uptime
      id: utime
```
to

```
    - platform: uptime
      name: Uptime
      id: utime_sensor

```
worked for me

fraserp, 2023-01-04:
Confirmed working

Dinth, 2023-01-04:
Works for me too.
Would you mind submitting a PR?

Badn1nja, 2024-01-20:
I just realised this is still an issue and have created this PR

nkitanov, 2024-01-23:
> I just realised this is still an issue and have created this PR

Thanks for your contribution. I can't test your code now, but if you can confirm it is building with the merged yaml I will close this issue.

Badn1nja, 2024-01-23:
It's paveldn's change I have just made the PR - but yes It's working on the latest ESPHome, I have used this change since early 2023

Badn1nja, 2024-01-23:
Sorry I should have made another branch for testing.... I have made a PR to fix this version..

Closed 2024-01-23.

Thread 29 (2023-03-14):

Consider orienting PMS7003 the other way down

divB0, 2023-03-14:
The current PMS7003 orientation is causing the photodiode to gather dust and limiting the life of the sensor. See this video for the explanation: https://www.youtube.com/watch?v=QgO0iWpK7Ho

nkitanov, 2024-01-23:
Unfortunately, I do not actively develop anymore this project so there is not a great change I will do any PCB redesign.

Closed 2024-01-23.

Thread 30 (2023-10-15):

Ordering

FredFeuerstein22, 2023-10-15:
Hi all. Is there any chance to order an assembeled board?

nkitanov, 2023-10-17:
Hello, unfortunately, I do not have any more parts for assembled boards. Only PCBs.

Closed 2023-10-17.

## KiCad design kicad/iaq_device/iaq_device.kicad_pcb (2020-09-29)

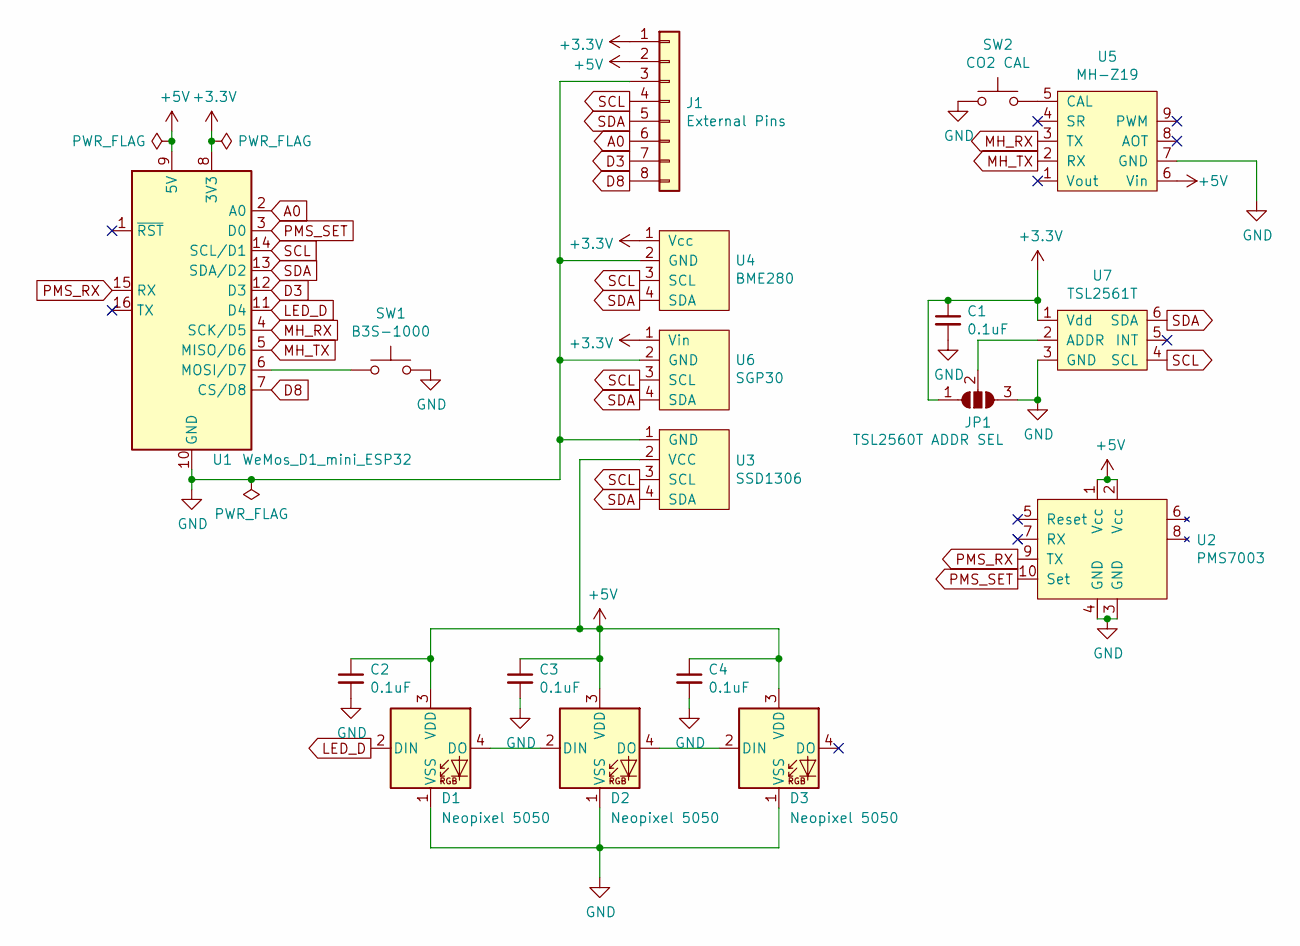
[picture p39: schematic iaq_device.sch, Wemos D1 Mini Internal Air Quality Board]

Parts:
C1, C2, C3, C4: 0.1uF; C_0805_2012Metric
D1, D2, D3: Neopixel 5050; LED_Inolux_IN-PI554FCH_PLCC4_5.0x5.0mm_P3.2mm
J1: External Pins; PinSocket_1x08_P2.54mm_Vertical_SMD_Pin1Left
JP1: TSL2560T ADDR SEL; SolderJumper-3_P1.3mm_Open_RoundedPad1.0x1.5mm_NumberLabels
SW1: B3S-1000; SW_SPST_B3S-1000
SW2: CO2 CAL; SW_SPST_B3U-1000P
U1: WeMos_D1_mini_ESP32; WEMOS_D1_surface
U2: PMS7003
U3: SSD1306
U4: BME280; BME280_breakout_6pin
U5: MH-Z19
U6: SGP30; SGP30_breakout_4pin
U7: TSL2561T

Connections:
+3V3: C1.1, J1.1, JP1.1 (A), U1.8 (3V3), U4.1 (Vcc), U6.1 (Vin), U7.1 (Vdd)
+5V: C2.1, C3.1, C4.1, D1.3 (VDD), D2.3 (VDD), D3.3 (VDD), J1.2, U1.9 (5V), U2.1 (Vcc), U2.2 (Vcc), U3.2 (VCC), U5.6 (Vin)
A0: J1.6, U1.2 (A0)
D3: J1.7, U1.12 (D3)
D8: J1.8, U1.7 (CS/D8)
GND: C1.2, C2.2, C3.2, C4.2, D1.1 (VSS), D2.1 (VSS), D3.1 (VSS), J1.3, JP1.3 (B), SW1.2, SW2.1, U1.10 (GND), U2.3 (GND), U2.4 (GND), U3.1 (GND), U4.2 (GND), U5.7 (GND), U6.2 (GND), U7.3 (GND)
LED_D: D1.2 (DIN), U1.11 (D4)
MH_RX: U1.4 (SCK/D5), U5.3 (TX)
MH_TX: U1.5 (MISO/D6), U5.2 (RX)
unnamed: D1.4 (DO), D2.2 (DIN)
unnamed: D2.4 (DO), D3.2 (DIN)
unnamed: JP1.2 (C), U7.2 (ADDR)
unnamed: SW1.1, U1.6 (MOSI/D7)
unnamed: SW2.2, U5.5 (CAL)
PMS_RX: U1.15 (RX), U2.9 (TX)
PMS_SET: U1.3 (D0), U2.10 (Set)
SCL: J1.4, U1.14 (SCL/D1), U3.3 (SCL), U4.3 (SCL), U6.3 (SCL), U7.4 (SCL)
SDA: J1.5, U1.13 (SDA/D2), U3.4 (SDA), U4.4 (SDA), U6.4 (SDA), U7.6 (SDA)

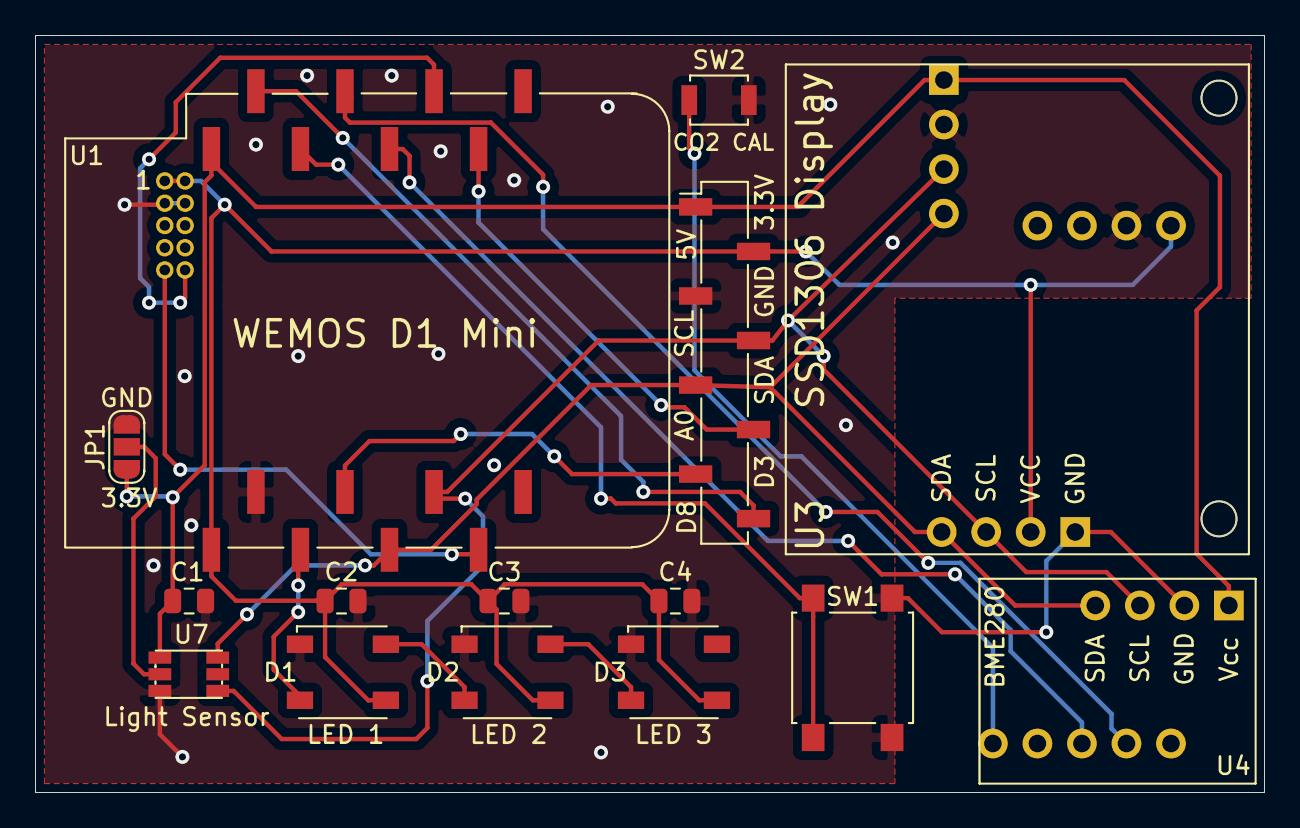
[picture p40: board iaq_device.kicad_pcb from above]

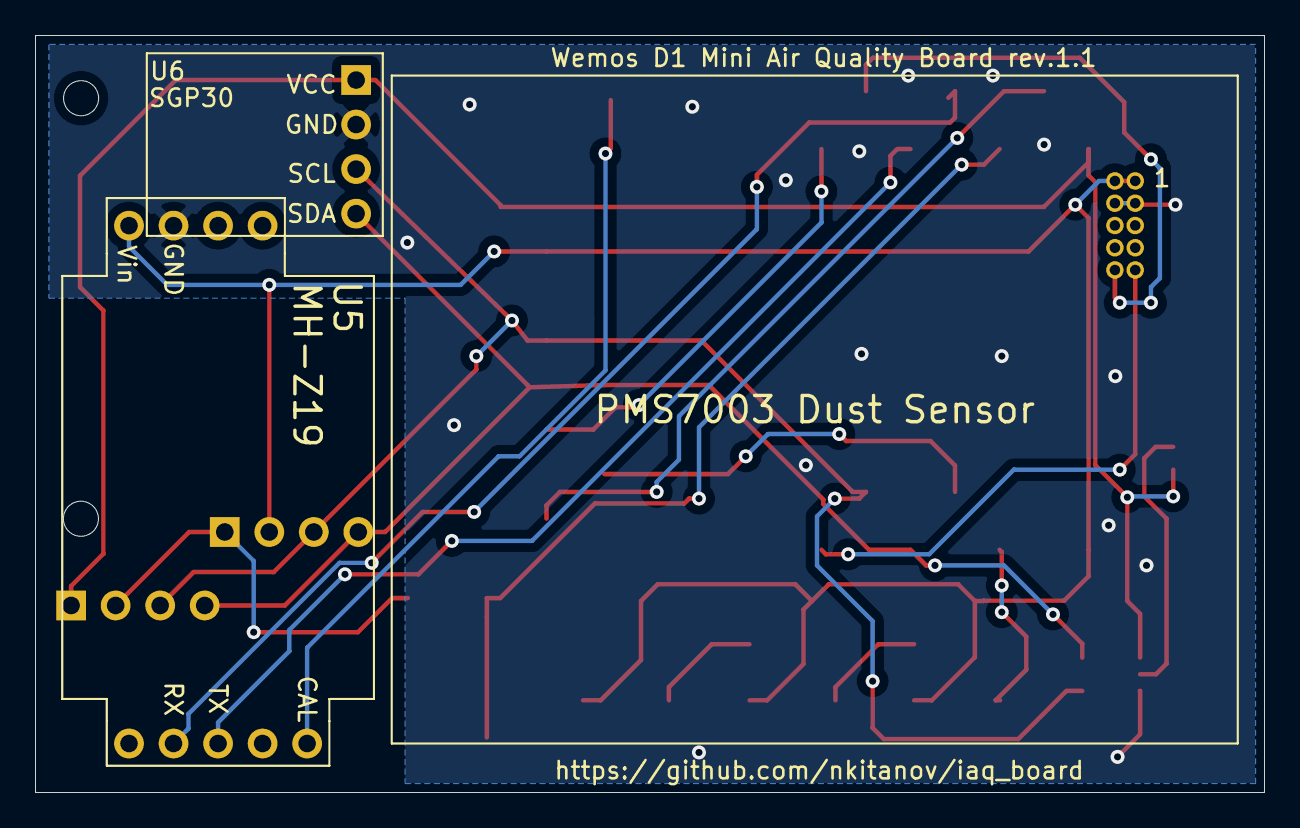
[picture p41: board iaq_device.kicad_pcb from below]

Board: 2 copper layers, 70.1 x 43.2 mm, 18 parts (3 on the bottom side), 18 nets.

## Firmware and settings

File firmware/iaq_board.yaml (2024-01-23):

esp32:
  board: wemos_d1_mini32
  framework:
    type: arduino

# Enable Home Assistant API
api:
  reboot_timeout: 0s
#  encryption:
#    key: ""
# Required for Home Assistant Intergration

ota:

wifi:
  ssid: !secret wifi_ssid
  password: !secret wifi_password

  # Enable fallback hotspot (captive portal) in case wifi connection fails
  ap:
    ssid: "IAQ Fallback Hotspot"
    password: "IfnXyerd2ufA"

captive_portal:
logger:
  baud_rate: 0

web_server:
  port: 80

substitutions:
  yaml_version: "1.1.3"

esphome:
  name: iaq-board
  friendly_name: IAQ Board
  # The library dep is added because of a bug in the neopixel library 
  # ver. 2.5.7. Can be removed when library is updated in future ver.
  # of esphome
  platformio_options:
    lib_deps: NeoPixelBus@2.6.0
    
  on_boot:
    then:
      - lambda: 'id(pm2_5).publish_state(1.0);'
      - lambda: 'id(co2).publish_state(400);'
      - light.control:
          id: led1
          brightness: 0.25
          state: on
      - light.control:
          id: led2
          brightness: 0.25
          state: on
      - light.control:
          id: led3
          brightness: 0.25
          state: on
      - delay: 1 min
      - script.execute: min_max_zero_script
        
script:
  - id: min_max_zero_script
    then: 
      - globals.set:
          id: pm_max
          value: '0.0'
      - globals.set:
          id: pm_min
          value: '300.0'
      - globals.set:
          id: co_max
          value: '0.0'
      - globals.set:
          id: co_min
          value: '5000.0'
      - globals.set:
          id: temp_min
          value: '50.0'
      - globals.set:
          id: temp_max
          value: '0.0'
button:
  - platform: template
    name: "Next Screen"
    id: iaq_screen_refresh
    # Optional variables:
    icon: "mdi:screen-rotatio"
    on_press:
      then:
        - lambda: |-
            if (id(button_mode) < 8) { id(button_mode) += 1; }
            else { id(button_mode) = 1; }

  - platform: template
    name: "Led Trigger"
    id: iaq_led_status
    # Optional variables:
    icon: "mdi:led-outline"
    on_press:
      then:
        - lambda: |-
            if (id(led_status)) { id(led_status) = false; }
            else { id(led_status) = true; } 
  
  - platform: template
    name: "Nightmode"
    id: iaq_nightmode
    # Optional variables:
    icon: "mdi:lightbulb-night"
    on_press:
      then:
        - lambda: |-
            if (id(night_mode)) { id(night_mode) = false; }
            else { id(night_mode) = true; }

  - platform: template
    name: "+/- Script"
    id: iaq_min_max_zero_script
    # Optional variables:
    icon: "mdi:refresh"
    on_press:
      then:
        - globals.set:
            id: min_max_zero
            value: 'true'
        - script.execute: min_max_zero_script
        - delay: 3s
        - globals.set:
            id: min_max_zero
            value: 'false'
        - logger.log: MIN/MAX Script enacted
        
globals:
  - id: button_mode
    type: int
    initial_value: '1'
  - id: brightness_correction
    type: float
    restore_value: yes
    initial_value: '0.15'
  - id: version
    type: bool
    initial_value: 'false'
  - id: led_status
    type: bool
    initial_value: 'true'
    restore_value: yes
  - id: display_on
    type: bool
    initial_value: 'true'
  - id: led_status_display
    type: bool
    initial_value: 'false'
  - id: night_mode
    type: bool
    restore_value: yes
  - id: night_mode_display
    type: bool
  - id: pm_min
    type: float
    initial_value: '300.0'
  - id: pm_max
    type: float
    initial_value: '0.0'
  - id: co_min
    type: float
    initial_value: '5000.0'
  - id: co_max
    type: float
    initial_value: '0.0'
  - id: temp_min
    type: float
    initial_value: '50.0'
  - id: temp_max
    type: float
    initial_value: '0.0'
  - id: min_max_zero
    type: bool
    initial_value: 'false'

font:
  - file: "fonts/Arial.ttf"
    id: arial
    size: 15
  - file: "fonts/Arial.ttf"
    id: arial30
    size: 30
  - file: "fonts/Arial.ttf"
    id: arial10
    size: 10

uart:
  - rx_pin: GPIO1
    baud_rate: 9600
    id: pms
  
  - rx_pin: GPIO18
    tx_pin: GPIO19
    baud_rate: 9600
    id: mh

i2c:
  scl: GPIO22
  sda: GPIO21
  frequency: 100kHz
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

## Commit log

2020-09-29 update kicad readme
2020-09-29 add gerbers folder
    [iaq_device-B_Cu.gbr, iaq_device-B_Mask.gbr, iaq_device-B_Paste.gbr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]
2020-12-13 update with assemble the PCB video
2021-02-05 docs: correct led state for worst air condition
2021-02-22 add note for fake MH-Z19B sensor and update the license info
2021-03-24 add display holder 3d model
    [display_holder_22mm.stl]
2021-04-05 update bom, add better photo of complete device
2021-04-21 Update case:
    - make channels for the PCB slacker so it can fit easily
    - increase angle of the pin so the case can stand more stable when angled
    - increase width of the pin to 12 mm
    [Stand_body.stl, Stand_pin.stl]
2021-11-08 Update README.md
    https://forum.kicad.info/t/warning-avoid-all-links-to-kicad-pcb-org-use-kicad-org/31521
2024-01-20 Update iaq_board.yaml
    Add HA Requirements and fix ;
    Firmware doesnt compile on 2022.12.X ESPHome - linking problem #27
    [iaq_board.yaml]
2024-01-23 Update iaq_board.yaml
    Added Virtual Buttons to simulate physical button hold functions
2024-01-23 Update iaq_board.yaml
    Update GPIO ID; button > buttonpcb
    error is ID 'button' conflicts with the name of an esphome integration, please use another ID name. Due to addition of virtual buttons being used
    [iaq_board.yaml]
2024-01-23 Update iaq_board.yaml
    Last PR pulled a bad version - this is tested as working;
    Changes- Changed Button in binary sensor to buttonPCB to fix a complication error with the ESPhome 'button:' id
    [iaq_board.yaml]
2024-01-23 Update iaq_board.yaml
    Added missing button to change to the next screen (Part of future idea to rotate the screen on an interval)
    [iaq_board.yaml]
2024-11-11 Revert "Update iaq_board.yaml for ESPHome 2024.10.0"
    This reverts commit 5ceda27facfb37ea441ae7d13d907912b07ded71.
    Revert this as it overwrite bugfixes
    [iaq_board.yaml]
